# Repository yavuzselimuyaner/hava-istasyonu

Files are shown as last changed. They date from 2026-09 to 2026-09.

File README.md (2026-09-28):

# Weather Station

**English** · [Türkçe](README.tr.md)

A device that measures outdoor temperature, humidity and pressure, publishes the readings to the internet over Wi-Fi, and shows them on a browser page.

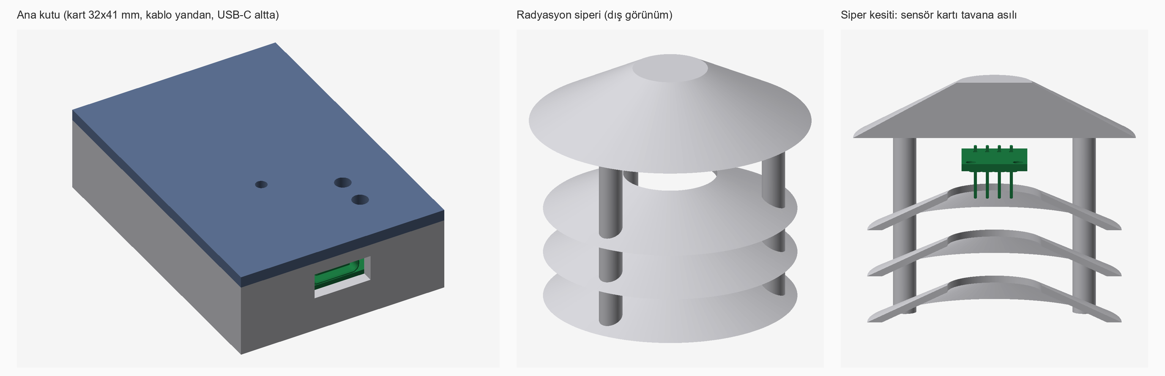
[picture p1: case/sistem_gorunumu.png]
Main enclosure and radiation shield


## What we built

### 1. Two boards
| Main board (32x41 mm) | Sensor board (14x16 mm) |
|---|---|
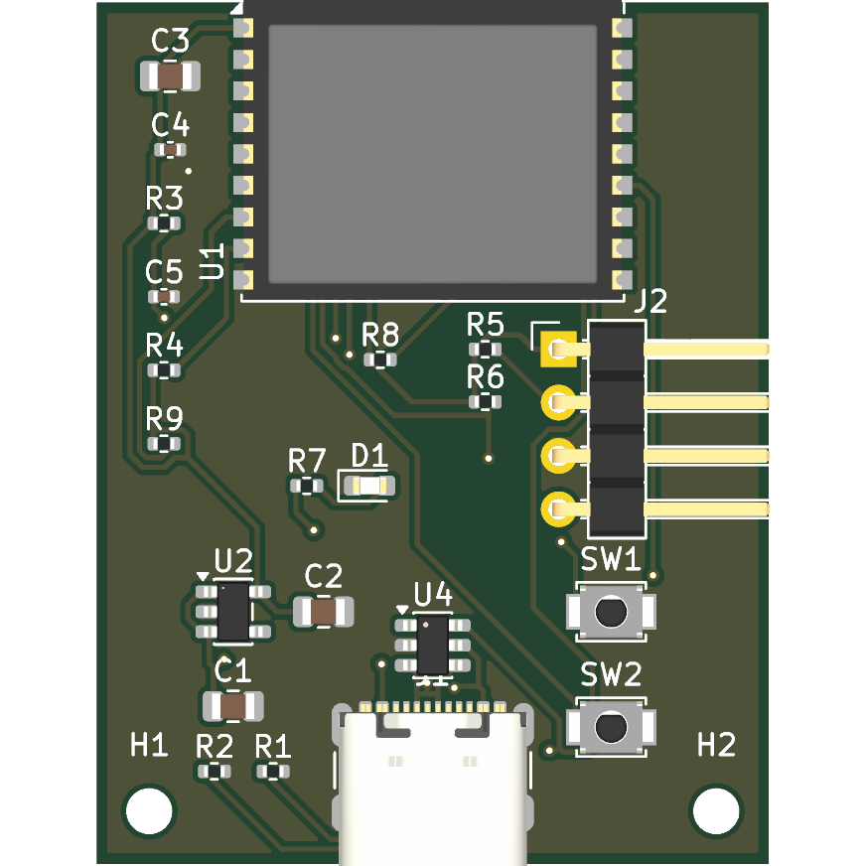
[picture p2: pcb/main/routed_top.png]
Main board
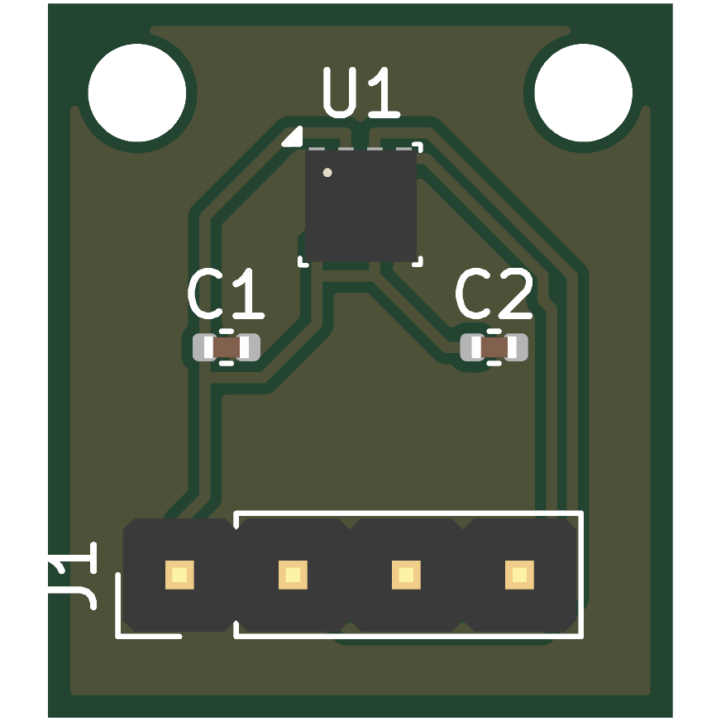
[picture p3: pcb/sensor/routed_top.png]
Sensor board
|  |  |

- **Main board:** ESP32-C3 (Wi-Fi processor module), USB-C, 3.3 V regulator, reset and boot buttons, status LED, and a 4-pin connector for the sensor. Held in the enclosure with two M2 screws.
- **Sensor board:** BME280 (temperature, humidity, pressure) and a connector. It is separate from the main board and connected by a cable, because the processor and regulator warm up and a sensor next to them would read the temperature too high.
- **Design decisions:** The antenna extends past the board edge (the manufacturer's recommendation). Pull-up resistors were added to IO2 and IO8, which set the ESP32-C3's boot mode (found during the datasheet audit). The connector is right-angled, so the cable exits sideways and the enclosure stays low. The first three pins of the connector match the order of common 3-wire sensor modules (VCC, DATA, GND).
- **Tools:** Circuit described in Python with SKiDL and turned into a KiCad schematic ([main board](pcb/main/hava_sematik.pdf), [sensor board](pcb/sensor/hava_sematik.pdf)); each board is built in KiCad from its schematic's netlist, and copper traces are auto-routed with Freerouting. Result: electrical rules check (ERC) 0 errors, design rules check (DRC) 0 violations, schematic and board match.

### 2. Enclosure and radiation shield
- **Main enclosure (37x54x15 mm):** openings for USB-C, the cable exit, the buttons and the LED.
- **Radiation shield (60 mm diameter, 52 mm high):** three conical plates and a roof, so the sun does not heat the sensor while air still flows through. The sensor board hangs from the roof and the cable exits at the bottom.
- Generated by scripts in FreeCAD, with dimensions read directly from the board. A **collision check** was run by intersecting KiCad's per-part 3D board model with the enclosure: no collisions.

### 3. Firmware
C with ESP-IDF. Connects to Wi-Fi, reads the sensor, and publishes the reading as JSON over MQTT (WebSocket + TLS, port 443). The sensor can be the BME280 (main board) or, as an alternative, a DHT22. A BME280 driver, the measurement compensation math, and DHT22 decoding were written.

### 4. Web page
A single-file page (`web/index.html`) that subscribes to the same MQTT topic, shows temperature, humidity and pressure, and displays the weather service's value next to them for comparison.

### 5. How we tested it
- **Datasheet audit (3 rounds):** Pin and circuit details of every part were compared with the datasheets; the issues found (unconnected strapping pins, a missing capacitor) were fixed.
- **Tests on a PC:** The BME280 math was compared with Bosch's datasheet example and the reference formula; the BME280 driver was run against a virtual sensor; DHT22 decoding was tested with datasheet examples.
- **Simulation (Wokwi):** Since the simulator has no BME280, readings were taken with an ESP32-S3 and a virtual DHT22, published over MQTT, and seen on the web page. A negative temperature (−17.9 °C) and about 3 minutes of continuous operation were tested.
- **Process:** The design and code were generated with an LLM (Claude); every step was checked with the tests above, and the issues they found were fixed.
- **Limitation:** Not yet tested on real hardware.

## Folders
| Folder | Contents |
|---|---|
| `pcb/main`, `pcb/sensor` | Main board and sensor board (KiCad, generation scripts) |
| `case` | Enclosure and radiation shield (FreeCAD scripts, images) |
| `firmware` | ESP-IDF project and tests |
| `web` | Browser page |
| `docs` | Design documents (`tasarim/`: requirements, part selection, datasheet audits, pin table) and build instructions (`CALISTIRMA.md`), in Turkish |

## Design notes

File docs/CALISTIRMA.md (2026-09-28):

# Çalıştırma ve yeniden üretme (Windows)

Gerekenler: KiCad 10 (`C:\Program Files\KiCad\10.0`), FreeCAD 1.1, Java 21, ESP-IDF v6.0.2, Python (SKiDL için `pcb/.venv`). Freerouting **v2.1.0** (Java 21 ile çalışan sürüm) `pcb/tools/` içinde olmalı (indirilmez, depoda yok).

## Kartlar (`pcb/main` veya `pcb/sensor` içinde)
Akış: SKiDL devre tanımı → **KiCad şematiği** → şematikten netlist → PCB yerleşimi → yol çizimi.
```
..\.venv\Scripts\python.exe gen_netlist.py
sh ../tools/check.sh .
"C:\Program Files\KiCad\10.0\bin\python.exe" build_board.py
"C:\Program Files\KiCad\10.0\bin\python.exe" route.py
"C:\Program Files\KiCad\10.0\bin\kicad-cli.exe" pcb drc --severity-error --schematic-parity -o drc_routed.rpt hava_routed.kicad_pcb
```
1. `gen_netlist.py`: devre tanımı (SKiDL) → `hava_skidl.net`.
2. `tools/check.sh` (Git Bash ile): `gen_schematic.py` ile `hava.kicad_sch` şematiğini üretir, KiCad ERC'sini çalıştırır (hata varsa durur), şematikten `hava.net` netlistini alır, bunun SKiDL netlistiyle bağlantı olarak birebir aynı olduğunu `tools/net_compare.py` ile doğrular ve `hava_sematik.pdf` çıktısını verir.
3. `build_board.py`: PCB'yi şematikten gelen `hava.net`'ten kurar; her footprint şematikteki sembolüne bağlanır.
4. `route.py`: Freerouting ile yollar → `hava_routed.kicad_pcb`.
5. DRC: `--schematic-parity` şematik ile kartın uyuştuğunu da kontrol eder.

Şematik KiCad'de `hava.kicad_pro` açılarak görülebilir. Sensör kartındaki tek ERC uyarısı beklenen bir durumdur: BME280'in SDO bacağı I2C adresini 0x76 yapmak için GND'ye bağlı; kütüphane bu bacağı "çift yönlü" tanımladığı için KiCad, GND'deki güç işaretiyle birlikte uyarı verir.
Freerouting deterministik değildir; sonuç her seferinde biraz farklı çıkar. Denemeden önce çalışan `hava_routed.kicad_pcb` dosyasını Git'e kaydet.

Pin tablosu (datasheet karşılaştırması için): `python pcb/pin_tablosu.py` çalıştırılınca `docs/tasarim/03-pin-tablosu.md` yeniden üretilir.

## Kutu ve siper (`case` içinde)
Sırasıyla `dump_board.py` (KiCad python), `make_main_case.py`, `make_shield.py`, `kicad-cli pcb export step ...`, `check_fit.py` (hepsi `freecadcmd` ile), `render_gorseller.py`. Komutlar betiklerin başındaki açıklamalarda.

## Firmware (`firmware` içinde, ESP-IDF PowerShell'inde)
```
idf.py -B build_c3 -D "SDKCONFIG=sdkconfig.c3" -D "IDF_TARGET=esp32c3" build
idf.py -B build_s3 -D "SDKCONFIG=sdkconfig.s3" -D "IDF_TARGET=esp32s3" build
idf.py -B build_wokwi -D "SDKCONFIG=sdkconfig.wokwi" -D "IDF_TARGET=esp32s3" -D "SDKCONFIG_DEFAULTS=sdkconfig.defaults;sdkconfig.defaults.esp32s3;sdkconfig.wokwi.defaults" build
```
Wi-Fi bilgileri: `idf.py menuconfig` → "Hava Sensor Dugumu" (bilgiler Git'e girmez). Wokwi için `firmware` klasörünü VS Code'da aç, "Wokwi: Start Simulator".

### T-Display-S3'e (gerçek donanım) yükleme
```
idf.py -B build_tdisplay -D "SDKCONFIG=sdkconfig.tdisplay" -D "IDF_TARGET=esp32s3" -D "SDKCONFIG_DEFAULTS=sdkconfig.defaults;sdkconfig.defaults.esp32s3;sdkconfig.tdisplay.defaults" menuconfig
```
Menüde Wi-Fi SSID/şifresini gir (bilgiler Git'e girmez), sonra:
```
idf.py -B build_tdisplay flash monitor
```
DHT22 verisi GPIO10'a, VCC 3V3'e, GND GND'ye bağlanır (SDA-VCC arası 10 kΩ pull-up önerilir). Kartın dahili ekranı (ST7789) otomatik devreye girer; sıcaklık, nem ve varsa basınç üç satır olarak gösterilir.

## Web
`web/index.html`'i tarayıcıda aç (MQTT.js CDN'den yüklenir). Yerel sunucu ile: `cd web && python -m http.server`.

## Testler (`firmware/test`, gcc)
```
gcc -Wall -Imock -o bme280_mock_test bme280_mock_test.c -lm
gcc -o dht22_test dht22_test.c
gcc -o bme_test bme_test.c -lm
```

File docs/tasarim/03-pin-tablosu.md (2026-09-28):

# Pin tablosu (karttan otomatik üretildi)

Bu tablo, şematikten (`pcb/*/hava.kicad_sch`) alınan `pcb/*/hava.net` dosyasından üretildi (`pcb/pin_tablosu.py`). Datasheet'lerdeki pin tablolarıyla karşılaştırma için: pin numarası, ad ve bağlı olduğu net. Karşılaştırma sonuçları `02-datasheet-denetimi.md` içinde.
Net adları: `+3V3`, `+5V`, `GND` güç hatları; `I2C_SDA/SCL` sensör; `USB_DP/DM` USB; `EN`, `BOOT` reset ve boot.

## Ana kart

### U1 — ESP32-C3-WROOM-02 (karşılaştır: modül datasheet'i pin tablosu; çip datasheet'i Tablo 3-3 boot)

| Pin | Adı (sembol) | Bağlı olduğu net |
|---|---|---|
| 1 | 3V3 | +3V3 |
| 2 | EN | EN |
| 3 | IO4 | I2C_SDA |
| 4 | IO5 | I2C_SCL |
| 7 | IO8 | IO8_PU |
| 8 | IO9 | BOOT |
| 9 | GND | GND |
| 11 | IO20/RXD | LED_IO |
| 13 | IO18 | USB_DM |
| 14 | IO19 | USB_DP |
| 16 | IO2 | IO2_PU |
| 19 | GND | GND |

Strapping kontrolü: **IO2 (pin 16)** ve **IO8 (pin 7)** birer 10 kΩ ile +3V3'e, **IO9 (pin 8)** BOOT hattına (10 kΩ pull-up + buton) bağlı olmalı. Tablodaki `IO2_PU` ve `IO8_PU` netleri R8 ve R9 dirençlerinin diğer ucudur; aşağıdaki direnç tablosunda R8/R9 satırlarında pin 1 = +3V3 görmelisin.

### U2 — AP2112K-3.3 (karşılaştır: AP2112 datasheet 'Pin Descriptions', SOT25)

| Pin | Adı (sembol) | Bağlı olduğu net |
|---|---|---|
| 1 | VIN | +5V |
| 2 | GND | GND |
| 3 | EN | +5V |
| 5 | VOUT | +3V3 |

### U4 — USBLC6-2SC6 (USB koruması)

| Pin | Adı (sembol) | Bağlı olduğu net |
|---|---|---|
| 1 | I/O1 | USB_DP |
| 2 | GND | GND |
| 3 | I/O2 | USB_DM |
| 4 | I/O2 | USB_DM |
| 5 | VBUS | +5V |
| 6 | I/O1 | USB_DP |

### J2 — sensör konnektörü (4 pin)

| Pin | Adı (sembol) | Bağlı olduğu net |
|---|---|---|
| 1 | 1 | +3V3 |
| 2 | 2 | I2C_SDA |
| 3 | 3 | GND |
| 4 | 4 | I2C_SCL |

### J1 — USB-C (CC1/CC2 pinleri her biri 5,1 kΩ ile GND'ye bağlı olmalı)

| Pin | Adı (sembol) | Bağlı olduğu net |
|---|---|---|
| A1 |  | GND |
| A12 |  | GND |
| A4 |  | +5V |
| A5 |  | USB_CC1 |
| A6 |  | USB_DP |
| A7 |  | USB_DM |
| A9 |  | +5V |
| B1 |  | GND |
| B12 |  | GND |
| B4 |  | +5V |
| B5 |  | USB_CC2 |
| B6 |  | USB_DP |
| B7 |  | USB_DM |
| B9 |  | +5V |
| SH |  | GND |

### Dirençler ve kondansatörler (değer → bağlı net çiftleri)

| Ref | Değer | Pin 1 | Pin 2 |
|---|---|---|---|
| C1 | 10uF | +5V | GND |
| C2 | 10uF | +3V3 | GND |
| C3 | 10uF | +3V3 | GND |
| C4 | 100nF | +3V3 | GND |
| C5 | 1uF | EN | GND |
| R1 | 5.1k | USB_CC1 | GND |
| R2 | 5.1k | USB_CC2 | GND |
| R3 | 10k | +3V3 | EN |
| R4 | 10k | +3V3 | BOOT |
| R5 | 4.7k | +3V3 | I2C_SDA |
| R6 | 4.7k | +3V3 | I2C_SCL |
| R7 | 1k | LED_IO | LED_A |
| R8 | 10k | +3V3 | IO2_PU |
| R9 | 10k | +3V3 | IO8_PU |

## Sensör kartı

### U1 — BME280 (karşılaştır: Bosch datasheet Bölüm 7, Tablo 35 ve Şekil 17)

| Pin | Adı (sembol) | Bağlı olduğu net |
|---|---|---|
| 1 | GND | GND |
| 2 | CSB | +3V3 |
| 3 | SDI | I2C_SDA |
| 4 | SCK | I2C_SCL |
| 5 | SDO | GND |
| 6 | VDDIO | +3V3 |
| 7 | GND | GND |
| 8 | VDD | +3V3 |

Beklenen (I2C): **CSB → +3V3**, **SDO → GND** (adres 0x76), VDD ve VDDIO ikisi de +3V3, iki pin GND.

### J1 — sensör konnektörü (ana kartın J2'si ile aynı sırada olmalı)

| Pin | Adı (sembol) | Bağlı olduğu net |
|---|---|---|
| 1 | 1 | +3V3 |
| 2 | 2 | I2C_SDA |
| 3 | 3 | GND |
| 4 | 4 | I2C_SCL |

### Kondansatörler

| Ref | Değer | Pin 1 | Pin 2 |
|---|---|---|---|
| C1 | 100nF | +3V3 | GND |
| C2 | 100nF | +3V3 | GND |

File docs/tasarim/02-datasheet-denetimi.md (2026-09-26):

# Datasheet denetimi

Kartlardaki bağlantılar ve değerler, parçaların datasheet'leriyle karşılaştırıldı. Kartın pin ve bağlantı listesi `03-pin-tablosu.md` dosyasında (karttan otomatik üretilir).

## Yöntem
- Datasheet metinleri PDF'ten çıkarıldı; şemalar, çizimler ve tablo görüntüleri sayfa sayfa görüntüye çevrilip okundu.
- Sayısal değerler her zaman PDF'in kendisinden alındı. Bir boot tablosunun otomatik bir özetle yanlış aktarılması, bunun gerekli olduğunu gösterdi.
- Karttaki her pin ve değer, datasheet'teki ilgili tabloya karşı işaretlendi.

| Belge | Sürüm |
|---|---|
| ESP32-C3 Series Datasheet | v2.4 |
| ESP32-C3-WROOM-02 ve WROOM-02U Datasheet | v1.7 |
| BME280 Data sheet (Bosch Sensortec) | dosya revizyonu 1.24 (sayfa altbilgisi DS001-23 rev 1.23) |
| AP2112 (Diodes Inc.) | DS39724 Rev. 2-2, Haziran 2017 |
| GCT USB4105 Product Drawing | Rev B3 |
| USBLC6-2 (STMicroelectronics) | Doc ID 11265 Rev 5, Ekim 2011 (üçüncü taraf kopyası) |

## Sonuçlar (6 kontrolün 6'sı uyuşuyor)

### 1) Strapping pinleri ve açılış modu
- **Kaynak:** Çip datasheet Tablo 3-1 ve 3-3 (s.30-31); modül datasheet Tablo 4-3.
- **Datasheet:** SPI boot: GPIO2=1, GPIO8=herhangi, GPIO9=1. İndirme modu: GPIO2=1, **GPIO8=1**, GPIO9=0. Varsayılan durum: GPIO2 ve GPIO8 "floating", GPIO9 zayıf pull-up. GPIO2'nin glitch'lere karşı yukarı çekilmesi önerilir.
- **Kart:** IO2 → 10 kΩ → +3V3; IO8 → 10 kΩ → +3V3; IO9 → BOOT hattı (10 kΩ pull-up ve buton).
- **Referans tasarım:** Modül datasheet Şekil 9-1 (s.34): IO2 ve IO8 için 10 kΩ ile VDD33'e çekme, IO9 için "Boot Option" başlığı. Kart referansla aynı. Modülün kendi şematiğinde (Şekil 8-1) EN, IO2 ve IO8 için dahili direnç yok; dış pull-up gerekli.

### 2) ESP32-C3-WROOM-02 modülü
- **Kaynak:** Modül datasheet Tablo 3-1 (s.10-11), Tablo 6-2, 6-4, Şekil 9-1.
- **Pinler:** 1=3V3, 2=EN, 3=IO4 (SDA), 4=IO5 (SCL), 7=IO8, 8=IO9, 9 ve 19=GND, 11=RXD (IO20), 12=TXD (IO21), 13=IO18 (USB D−), 14=IO19 (USB D+), 16=IO2. Pin tablosuyla birebir aynı.
- **EN:** "EN pini floating bırakılmamalı"; önerilen RC 10 kΩ ve 1 µF (s.34 metni). Kartta 10 kΩ ve 1 µF. Aynı sayfadaki şekilde C4 = 0,1 µF yazıyor; metin ile şekil tutarsız, metne uyuldu.
- **Güç:** VDD33 3,0–3,6 V; harici kaynak en az 0,5 A (Tablo 6-2). Wi-Fi tepe akımı 345 mA (802.11b 1 Mbps @20,5 dBm, Tablo 6-4). 600 mA'lik regülatör yeterli.
- **Besleme kondansatörleri:** Referansta 10 µF ve 0,1 µF; kartta 10 µF ve 100 nF.
- **USB hatları:** Referans tasarımda D+ ve D− üzerinde 0 Ω seri direnç var; kartta seri direnç yok, USBLC6 koruması var. Datasheet ikisini de zorunlu kılmıyor.

### 3) BME280
- **Kaynak:** Bölüm 7, Tablo 35 (pin açıklaması), Şekil 17 (I2C bağlantısı), Şekil 21 (lehim deseni, s.43).
- **Pinler:** 1=GND, 2=CSB, 3=SDI, 4=SCK, 5=SDO, 6=VDDIO, 7=GND, 8=VDD. I2C için CSB→VDDIO, SDO→GND (adres 0x76), VDD ve VDDIO için ayrı 100 nF, pull-up için 4,7 kΩ. Kartlarla aynı.
- **Footprint:** Önerilen lehim deseni: pad 0,5 x 0,35 mm, aralık 0,65 mm, merkez ofseti 1,025 mm. KiCad footprint'i (Bosch_LGA-8_2.5x2.5mm_P0.65mm_ClockwisePinNumbering) aynı boyutlarda, 90° döndürülmüş ve pin 1 konumu doğru.

### 4) AP2112K-3.3 (SOT25)
- **Kaynak:** Sayfa 2 (Pin Descriptions ve Blok Şeması), Not 4, Mutlak Azami Değerler, Önerilen Çalışma Koşulları.
- **Pinler:** 1=VIN, 2=GND, 3=EN, 5=VOUT. Blok şemada (D = SOT25) aynı numaralar. 4. pin datasheet tablosunda tanımlı değil, bağlantısız bırakıldı.
- **Değerler:** Önerilen VIN 2,5–6,0 V, mutlak azami 6,5 V (USB 5 V için uygun). Tipik uygulama giriş ve çıkışta 1 µF; 1 µF seramikse X7R veya X5R (Not 4). θJA (SOT25) = 184 °C/W. EN yüksek eşiği 1,5 V (kartta EN, VIN'e bağlı).
- **Kondansatör:** Datasheet yalnızca 1 µF'ı örnekliyor, üst sınır vermiyor. Kartta 10 µF (X5R/X7R seçilmeli); bir tasarım tercihi, datasheet'le çelişmez.

### 5) USB-C alıcı (GCT USB4105)
- **Kaynak:** Product Drawing, sayfa 1, pin tablosu ve "Recommended PCB Layout" ölçüleri.
- **Pinler:** A1, A12, B1, B12 = GND; A4, A9, B4, B9 = VBUS; A5 = CC1; B5 = CC2; A6/B6 = D+; A7/B7 = D−; A8 = SBU1; B8 = SBU2; kabuk = GND. Karttaki bağlantılarla birebir aynı (SBU pinleri bağlantısız).
- **Footprint ölçüleri:** Önerilen PCB deseni ile KiCad footprint'i sayısal karşılaştırıldı: pad merkezleri ±3,20 / ±2,40 / ±1,75 / ±1,25 / ±0,75 / ±0,25 mm, pad genişlikleri 0,60 ve 0,30 mm, pad boyu 1,15 mm, konumlandırma delikleri Ø0,65 mm (aralık 5,78 mm), kabuk delikleri 8,64 mm aralıkta (üstte 1,0x2,1 mm oval, delik 0,6x1,7; altta 1,0x1,8 mm oval, delik 0,6x1,4) ve delikler arası 4,18 mm: hepsi çizimle aynı.
- **Kart kenarı:** Çizimde kart kenarı alt kabuk delik merkezinin 2,60 mm ötesinde; kartta konnektör kenardan 3,5 mm içeride, çizime göre 3,675 mm olmalı. Kabuk 0,175 mm fazla dışarı taşıyor; çizimin ±0,05 mm toleransının dışında, bu bilinen bir sapma olarak not edildi.
- **CC dirençleri:** Çizimde yok. USB Type-C kuralı: cihaz (sink) tarafında her CC pini ayrı ayrı 5,1 kΩ ile GND'ye bağlanır. Kartta iki ayrı 5,1 kΩ direnç.

### 6) USBLC6-2SC6 (SOT23-6L)
- **Kaynak:** ST datasheet, Şekil 1 (üstten görünüş, fonksiyonel şema).
- **Pinler:** 1 ve 6 = I/O1, 2 = GND, 3 ve 4 = I/O2, 5 = VBUS. Kartta pin 1 ve 6 USB_DP, pin 3 ve 4 USB_DM, pin 2 GND, pin 5 +5V: birebir aynı (`03-pin-tablosu.md`).
- **Belge:** ST'nin resmi sitesi bu denetimde açılamadı; içeriği ST datasheet'inin bir kopyasından (üçüncü taraf, ST logolu, Doc ID 11265 Rev 5) okundu. Şekil ve pin numaraları sayfa görüntüsünden doğrulandı.

## Denetimde bulunan ve düzeltilen hatalar
| Bulgu | Düzeltme |
|---|---|
| IO8 bağlantısız bırakılmıştı; indirme modu için GPIO8=1 şart, varsayılanı belirsiz (floating) | IO8'e 10 kΩ pull-up |
| IO2 bağlantısız; datasheet yukarı çekilmesini öneriyor | IO2'ye 10 kΩ pull-up |
| BME280 için tek 100 nF vardı; Bosch VDD ve VDDIO için ayrı ayrı gösteriyor | İkinci 100 nF eklendi |
| Modülün GPIO sayısı yanlış aktarılmıştı (22 yerine 15) | Düzeltildi |
| AP2112 SOT25 4. pini "NC" diye yazılmıştı; datasheet tanımlamıyor | Belgeler düzeltildi |
| Wi-Fi tepe akımı çip datasheet'inde 335 mA, modülde 345 mA | Modül değeri esas alındı |
| Anten kartın içinde kalmıştı; üretici anteni kart kenarından dışarı taşırmayı öneriyor | Modül kaydırıldı, anten kart dışında |

## Hesaplar
- **I2C kablo yükü:** Standart mod için yükselme süresi üst sınırı 1000 ns ve hat sığası üst sınırı 400 pF (I2C spesifikasyonundan bilgi; belge bu çalışmada açılmadı). 4,7 kΩ pull-up ile ~250 pF bütçe var. 40 cm kablo yaklaşık 20 pF, iki cihaz girişi birkaç on pF: bütçenin çok altında. Kablo 1 m'yi geçmemeli.
- **Regülatör ısınması:** SOT25 θJA = 184 °C/W, giriş-çıkış farkı 1,7 V. Ortalama 100 mA'de ~0,17 W, yaklaşık 31 °C yükselme; 345 mA tepe akım kısa süreli.
- **Kutu ve siper çakışması:** KiCad'in parçalı 3D kart modeli FreeCAD'de kutu ve siperle kesiştirildi: çakışma yok. Kontrolün doğruluğu, kartı bilerek duvara kaydırıp çakışmanın bulunmasıyla sınandı.

## Açıkta kalanlar ve bilinen sınırlar
- **USB Type-C 5,1 kΩ kuralı:** Birkaç ikincil kaynakla teyit edildi; USB-IF spesifikasyonunun kendisi açılmadı.
- **Anten yasak bölgesi:** Ölçü, footprint'in courtyard'ından alındı; Espressif donanım tasarım rehberinin ilgili bölümü ayrıca incelenmedi.
- **USB izleri:** Ana kartta modülün altından geçiyor; kritik hatlar için elle yönlendirme daha iyi olurdu.
- **Siper:** Yağmur koruması sınırlı (tavan ile en üst plaka arasında açık boşluk).
- **Kutu:** Vidalar modellenmedi; kapak sürtünmeli çıtayla oturur; anten çevresindeki plastiğin etkisi ölçülmedi.

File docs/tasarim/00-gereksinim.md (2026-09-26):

# Gereksinim

Dışarıdaki bir sensörle sıcaklık, nem ve basıncı ölçen ve bu bilgiyi internete yayınlayan bir cihaz tasarla. Bilgi bir tarayıcı sayfasında görülebilmeli. Cihaz Wi-Fi ile bağlanacak, USB-C ile beslenecek. Sensör, cihazın ısınan parçalarından uzakta ve güneşten korunmuş olmalı: sensör ayrı küçük bir kartta, kabloyla bağlı olacak. Kartlar 2 katmanlı olacak. Çıktılar: KiCad kartları, kutu ve sensör koruması (radyasyon siperi), firmware ve basit bir web sayfası.

## Kısıtlar ve kararlar
- **Kablosuz bağlantı:** Wi-Fi (2,4 GHz). Anten performansı için hazır, sertifikalı bir modül kullanılır.
- **Güç:** USB-C, 5 V. Kart üzerinde 3,3 V'a indirilir.
- **Ölçüm:** Sıcaklık, bağıl nem, basınç; tek bir I2C sensörüyle.
- **Isıl ayrım:** İşlemci ve regülatör ısınır; sensör bu ısıdan ve doğrudan güneşten uzak durmalı. Bu yüzden sensör ana karttan ayrı, kabloyla bağlı bir kartta.
- **Haberleşme:** Ölçümler MQTT ile yayınlanır (WebSocket ve TLS üzerinden, 443 portu), tarayıcı sayfası aynı konuyu dinler.
- **Web sayfası:** Bilerek çok basit; tek dosya, sunucu ve veri tabanı yok.
- **Mekanik:** Kart kutuya vidayla sabitlenir (2 adet M2 montaj deliği); sensör kartı da kendi montaj deliklerine sahiptir.

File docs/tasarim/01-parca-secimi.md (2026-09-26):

# Parça seçimi

Her parça için seçilen ve elenen alternatifler ve gerekçe. Datasheet doğrulaması `02-datasheet-denetimi.md` içinde.

## İşlemci (MCU)
| Aday | Değerlendirme |
|---|---|
| **ESP32-C3-WROOM-02** | Seçildi. Wi-Fi ve BLE içinde, sertifikalı PCB anten modülü, USB Serial/JTAG dahili (ek çip gerekmez), ucuz, KiCad'de sembol ve footprint hazır. Modülde 15 GPIO pini var, bu iş için yeterli. |
| ESP32-S3-WROOM-1 | Bu iş için gereksiz güçlü, daha pahalı ve daha yüksek akımlı. |
| ESP32-S2-MINI-1 | Wi-Fi var, BLE yok, C3'e göre belirgin bir avantajı yok. |
| RP2040 + ayrı Wi-Fi modülü | İki çip, ek flash ve kristal gerekir; karmaşıklık ve hata riski artar. |

Çıplak çip yerine hazır modül seçildi: anten, kristal ve flash zaten entegre ve sertifikalı; RF tasarımı yeniden yapılmıyor.

## Sensör
| Aday | Değerlendirme |
|---|---|
| **BME280** | Seçildi. Sıcaklık, nem ve basınç tek çipte, I2C, 2,5 x 2,5 mm LGA. |
| SHT31 / SHT4x + BMP280 | Nem ve sıcaklık doğruluğu daha iyi olabilir ama iki çip gerekir. |
| AHT20 + BMP280 | İki çip. |
| DHT22 | Basınç yok, tek tel protokol; firmware'de alternatif sensör olarak desteklenir. |

BME280'in kendi ısınması ölçümü etkileyebilir; bu yüzden ısı kaynaklarından uzak, ayrı bir kartta.

## Regülatör
| Aday | Değerlendirme |
|---|---|
| **AP2112K-3.3** | Seçildi. 600 mA, SOT-23-5, yaygın. Modülün en yüksek Wi-Fi akımı ~345 mA, önerilen harici kaynak akımı 0,5 A: yeterli. |
| ME6211C33M5 | 500 mA; marj daha dar. |
| XC6220B331MR | 700 mA; daha pahalı. |

## USB
- **USB-C alıcı (GCT USB4105, 16 pin, USB 2.0):** Güç ve programlama/log.
- **CC1 ve CC2:** Her biri ayrı ayrı 5,1 kΩ ile GND'ye (cihaz tarafı, 5 V).
- **USBLC6-2SC6:** USB veri hatlarını ve VBUS'ı ESD'ye karşı korur.

## Diğer parçalar
- **EN devresi:** 10 kΩ pull-up ve 1 µF (üretici önerisi), reset butonu.
- **Boot:** IO9 için buton ve 10 kΩ pull-up.
- **Strapping pull-up'ları:** IO2 ve IO8 için 10 kΩ (açılış modunu belirleyen pinler).
- **I2C pull-up'ları:** SDA ve SCL için 4,7 kΩ.
- **Kondansatörler:** 3V3 hattında 10 µF ve 100 nF; regülatörde giriş ve çıkışta 10 µF; BME280 için iki adet 100 nF (VDD ve VDDIO).
- **Durum LED'i** ve 1 kΩ direnç.
- **Sensör konnektörü:** 1x4, 2,54 mm, dik açılı (kablo yandan çıksın, kutu alçak kalsın). Pin sırası: 1=3V3, 2=SDA/DATA, 3=GND, 4=SCL; ilk üç pin yaygın 3 telli sensör modüllerinin (VCC, DATA, GND) sırasına denk gelir.
- **Montaj delikleri:** Her kartta 2 adet M2.

## Sensör kartı
BME280, 2 x 100 nF, aynı 4 pinli konnektör ve 2 montaj deliği. I2C pull-up dirençleri ana kartta.

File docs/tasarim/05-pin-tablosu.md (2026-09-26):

# Pin tablosu (karttan otomatik üretildi)

Bu tablo `pcb/*/hava.net` dosyasından üretildi (`pcb/pin_tablosu.py`). Datasheet'teki pin tablosuyla yan yana koyup **kendi gözünle** karşılaştır: pin numarası, ad ve bağlı olduğu net uyuşuyor mu?
Net adları: `+3V3`, `+5V`, `GND` güç hatları; `I2C_SDA/SCL` sensör; `USB_DP/DM` USB; `EN`, `BOOT` reset ve boot.

## Ana kart

### U1 — ESP32-C3-WROOM-02 (karşılaştır: modül datasheet'i pin tablosu; çip datasheet'i Tablo 3-3 boot)

| Pin | Adı (sembol) | Bağlı olduğu net |
|---|---|---|
| 1 | 3V3 | +3V3 |
| 2 | EN | EN |
| 3 | IO4 | I2C_SDA |
| 4 | IO5 | I2C_SCL |
| 7 | IO8 | N$4 |
| 8 | IO9 | BOOT |
| 9 | GND | GND |
| 11 | IO20/RXD | LED_IO |
| 13 | IO18 | USB_DM |
| 14 | IO19 | USB_DP |
| 16 | IO2 | N$3 |
| 19 | GND | GND |

Strapping kontrolü: **IO2 (pin 16)** ve **IO8 (pin 7)** birer 10 kΩ ile +3V3'e, **IO9 (pin 8)** BOOT hattına (10 kΩ pull-up + buton) bağlı olmalı. Tablodaki `N$3` (IO2) ve `N$4` (IO8) otomatik adlı netlerdir: R8 ve R9 dirençlerinin diğer ucudur, aşağıdaki direnç tablosunda R8/R9 satırlarında pin 1 = +3V3 görmelisin.

### U2 — AP2112K-3.3 (karşılaştır: AP2112 datasheet 'Pin Descriptions', SOT25)

| Pin | Adı (sembol) | Bağlı olduğu net |
|---|---|---|
| 1 | VIN | +5V |
| 2 | GND | GND |
| 3 | EN | +5V |
| 5 | VOUT | +3V3 |

### U4 — USBLC6-2SC6 (USB koruması)

| Pin | Adı (sembol) | Bağlı olduğu net |
|---|---|---|
| 1 | I/O1 | USB_DP |
| 2 | GND | GND |
| 3 | I/O2 | USB_DM |
| 4 | I/O2 | USB_DM |
| 5 | VBUS | +5V |
| 6 | I/O1 | USB_DP |

### J2 — sensör konnektörü (4 pin)

| Pin | Adı (sembol) | Bağlı olduğu net |
|---|---|---|
| 1 | 1 | +3V3 |
| 2 | 2 | I2C_SDA |
| 3 | 3 | GND |
| 4 | 4 | I2C_SCL |

### J1 — USB-C (CC1/CC2 pinleri her biri 5,1 kΩ ile GND'ye bağlı olmalı)

| Pin | Adı (sembol) | Bağlı olduğu net |
|---|---|---|
| A1 |  | GND |
| A12 |  | GND |
| A4 |  | +5V |
| A5 |  | N$1 |
| A6 |  | USB_DP |
| A7 |  | USB_DM |
| A9 |  | +5V |
| B1 |  | GND |
| B12 |  | GND |
| B4 |  | +5V |
| B5 |  | N$2 |
| B6 |  | USB_DP |
| B7 |  | USB_DM |
| B9 |  | +5V |
| SH |  | GND |

### Dirençler ve kondansatörler (değer → bağlı net çiftleri)

| Ref | Değer | Pin 1 | Pin 2 |
|---|---|---|---|
| C1 | 10uF | +5V | GND |
| C2 | 10uF | +3V3 | GND |
| C3 | 10uF | +3V3 | GND |
| C4 | 100nF | +3V3 | GND |
| C5 | 1uF | EN | GND |
| R1 | 5.1k | N$1 | GND |
| R2 | 5.1k | N$2 | GND |
| R3 | 10k | +3V3 | EN |
| R4 | 10k | +3V3 | BOOT |
| R5 | 4.7k | +3V3 | I2C_SDA |
| R6 | 4.7k | +3V3 | I2C_SCL |
| R7 | 1k | LED_IO | N$5 |
| R8 | 10k | +3V3 | N$3 |
| R9 | 10k | +3V3 | N$4 |

## Sensör kartı

### U1 — BME280 (karşılaştır: Bosch datasheet Bölüm 7, Tablo 35 ve Şekil 17)

| Pin | Adı (sembol) | Bağlı olduğu net |
|---|---|---|
| 1 | GND | GND |
| 2 | CSB | +3V3 |
| 3 | SDI | I2C_SDA |
| 4 | SCK | I2C_SCL |
| 5 | SDO | GND |
| 6 | VDDIO | +3V3 |
| 7 | GND | GND |
| 8 | VDD | +3V3 |

Beklenen (I2C): **CSB → +3V3**, **SDO → GND** (adres 0x76), VDD ve VDDIO ikisi de +3V3, iki pin GND.

### J1 — sensör konnektörü (ana kartın J2'si ile aynı sırada olmalı)

| Pin | Adı (sembol) | Bağlı olduğu net |
|---|---|---|
| 1 | 1 | +3V3 |
| 2 | 2 | I2C_SDA |
| 3 | 3 | GND |
| 4 | 4 | I2C_SCL |

### Kondansatörler

| Ref | Değer | Pin 1 | Pin 2 |
|---|---|---|---|
| C1 | 100nF | +3V3 | GND |
| C2 | 100nF | +3V3 | GND |

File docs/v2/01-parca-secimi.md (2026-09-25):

# v1 Adım 1 — Parça Seçimi (Agent: parça seçici)

> **Not:** Bu belge eski (v1) tasarım için yazıldı: cihaz ekranlıydı ve internetten veri çekiyordu. **Ekran, pin planı ve "internetten çekme" kısımları ESKİDİR.** MCU/sensör/regülatör seçimi ve datasheet bulguları v2 için de GEÇERLİDİR. Güncel gereksinim: `00-gereksinim.md`.

Girdi: yalnızca 00-gereksinim.md. Kullanıcının elindeki donanım (T-Display, ESP32-S3) bilerek DİKKATE ALINMADI.
Kısıt notu: Ağ erişimi olmadan yazıldı; JLCPCB stok/fiyat ve datasheet değerleri DOĞRULANMADI. Bunlar denetçi adımının işidir (aşağıda işaretli).

## 1. MCU
| Aday | Artı | Eksi |
|---|---|---|
| ESP32-C3-WROOM-02 | Wi-Fi + BLE, sertifikalı anten modülü, tek çekirdek RISC-V yeterli, USB Serial/JTAG dahili (ek çip yok), ucuz, KiCad'de sembol+footprint var | 22 GPIO civarı; ihtiyaç için yeterli |
| ESP32-S3-WROOM-1 | Daha çok GPIO, daha güçlü | Bu iş için gereksiz, daha pahalı, daha yüksek akım |
| ESP32-S2-MINI-1 | Wi-Fi, USB OTG | BLE yok, C3'ten belirgin avantaj yok |
| RP2040 + ayrı Wi-Fi modülü | Ucuz MCU | İki çip, ek flash/kristal, karmaşıklık ve hata riski |

**Seçim: ESP32-C3-WROOM-02** (RF_Module:ESP32-C3-WROOM-02). Gerekçe: gereksinim yalnızca Wi-Fi, bir I2C sensörü ve bir SPI ekran; en az parçayla en düşük risk. Sertifikalı modül, anten tasarımı riskini kaldırır.
- Doğrulanacak: pin ataması (strapping GPIO2/8/9), USB pinleri GPIO18/19, tepe akım.

## 2. Sensör
| Aday | Not |
|---|---|
| BME280 | Sıcaklık+nem+basınç tek çipte, I2C, 2.5x2.5 mm LGA (elle lehimlenmez, montaj hizmetiyle olur) |
| SHT31/SHT4x + BMP280 | İki çip, daha iyi nem/sıcaklık doğruluğu, daha çok parça |
| AHT20 + BMP280 | Ucuz ama iki çip |

**Seçim: BME280** (Sensor:BME280). Gerekçe: gereksinim üç ölçümü istiyor, tek çip en az parça. Risk: kartın kendi ısısı sıcaklığı yükseltir, sensör ısı kaynaklarından uzağa ve kart kenarına konmalı; klon/sahte BME280 riski (BMP280 olarak çıkabilir).

## 3. Regülatör
| Aday | Not |
|---|---|
| AP2112K-3.3 | 600 mA, SOT-23-5, yaygın |
| ME6211C33M5 | 500 mA, çok yaygın ve ucuz |
| XC6220B331MR | 700 mA, daha pahalı |

**Seçim: AP2112K-3.3.** Gerekçe: Wi-Fi TX tepe akımı (~350 mA civarı C3 için) altında yeterli marj. Doğrulanacak: datasheet'te tepe akım ve dropout, çıkış kondansatörü gereksinimi.

## 4. USB-C
16 pinli USB 2.0 Type-C girişi (Connector:USB_C_Receptacle_USB2.0_16P), CC1/CC2 için 5.1 kΩ (5 V sink), D+/D− doğrudan C3'ün USB pinlerine. Ek ESD koruması (USBLC6-2SC6) eklenir.
- Doğrulanacak: JLCPCB'de montaj yapılan uygun bir 16P konnektör var mı, footprint uyumu.

## 5. Ekran (KARAR)
| Seçenek | Not |
|---|---|
| Harici 1.3" ST7789 SPI 240x240 modül, 8 pin header | Karta ekran flexi/FPC routing riski yok, modül ucuz ve yaygın |
| Karta doğrudan bağlı ekran (FPC) | Daha kompakt, ama FPC footprint ve sürücü riski yüksek |
| 0.96" OLED I2C | Sensörle aynı I2C hattı, az pin; ama küçük, hava verisi için yetersiz |

**Seçim: harici 1.3" ST7789 SPI modül, 8 pin header.** Gerekçe: yerleşim ve montaj riskini azaltır. Bu karar gereksinimde açık bırakıldığı için agent'a aittir.

## 6. Yardımcı parçalar
- Reset (EN) ve BOOT (GPIO9) butonları, 10 kΩ pull-up'lar, EN için 1 µF.
- I2C pull-up 4.7 kΩ ×2.
- Bypass kondansatörleri (MCU, sensör, regülatör giriş/çıkış).
- Durum LED'i + direnç.

## Denetçiye devredilen kontrol listesi
- [ ] ESP32-C3-WROOM-02 datasheet: pin isimleri, strapping, EN devresi, USB pinleri, anten keepout
- [ ] BME280 datasheet: adres seçimi (SDO), CSB pinini I2C modu için bağlama, güç/decoupling
- [ ] AP2112K datasheet: çıkış C değeri, EN kullanımı
- [ ] JLCPCB: parçaların montaj kataloğunda olup olmadığı, temel/genişletilmiş parça durumu

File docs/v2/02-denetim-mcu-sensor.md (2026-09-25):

# v1 Adım 2 — Denetim (Agent: denetçi)

> **Not:** Bu belge eski (v1) tasarım için yazıldı: cihaz ekranlıydı ve internetten veri çekiyordu. **Ekran, pin planı ve "internetten çekme" kısımları ESKİDİR.** MCU/sensör/regülatör seçimi ve datasheet bulguları v2 için de GEÇERLİDİR. Güncel gereksinim: `00-gereksinim.md`.

Kaynaklar: Espressif ESP32-C3-WROOM-02 datasheet (documentation.espressif.com), Bosch BME280 datasheet rev 1.24, Diodes AP2112 datasheet DS39724, JLCPCB parça sayfaları (arama sonuçları). Sonuçlar web aramasının özetlerine dayanır; kritik sayılar tasarım kilitlenmeden önce PDF'den elle teyit edilmelidir.

## Doğrulananlar
| Konu | Bulgu | Durum |
|---|---|---|
| C3 modül pinleri | 3V3=1, EN=2, IO4-7=3-6, IO8=7, IO9=8, GND=9, IO10=10, RXD/IO20=11, TXD/IO21=12, IO18(USB D-)=13, IO19(USB D+)=14, IO3=15, IO2=16, IO1=17, IO0=18, GND=19 | KiCad sembolü ve footprint ile TAM UYUMLU |
| Strapping | GPIO2, GPIO8, GPIO9 | Doğrulandı; bu üç pin sinyal olarak kullanılmayacak (GPIO9 = BOOT butonu) |
| USB | GPIO18/19 dahili USB Serial/JTAG; GPIO olarak yeniden atanırsa USB-JTAG kapanır | Doğrulandı; bu iki pin USB'ye ayrılmalı |
| EN devresi | Önerilen RC: 10 kΩ + 1 µF | Doğrulandı, taslakla aynı |
| BME280 I2C | CSB → VDDIO ile I2C modu; SDO GND ise 0x76, VDDIO ise 0x77; SDO bağlantısız bırakılamaz | Doğrulandı, taslakla aynı |
| AP2112 | 600 mA (min) sürekli akım; çıkışta 1 µF X7R/X5R önerilir | Doğrulandı; planlanan 10 µF ile uyumluluk (ESR/stabilite) datasheet'ten ayrıca kontrol edilecek |

## Bulunan hatalar (parça seçici agent'ın yanlışları)
1. **"22 GPIO" iddiası yanlış.** Çip 22 GPIO'ya sahip ama WROOM-02 modülünde 15 GPIO pini var (IO0-IO10, RXD/IO20, TXD/IO21, IO18, IO19).
2. **Güç marjı ince.** Datasheet dış kaynak için en az 0.5 A istiyor; AP2112K-3.3'ün garantili akımı 600 mA. Marj yalnızca 100 mA. Kabul edilebilir ama not düşülmeli: yeterli çıkış kondansatörü ve kısa yol; sorun çıkarsa daha güçlü LDO.
3. **Pin bütçesi sıkı.** Kullanılabilir sinyal pini: IO0,1,3,4,5,6,7,10 (8 pin) + UART pinleri IO20,IO21 (USB konsol kullanıldığı için serbest) = 10. Strapping (2,8,9) ve USB (18,19) hariç.

## Pin planı (v1, onaylanacak)
| Sinyal | Pin |
|---|---|
| I2C SDA / SCL | IO4 / IO5 |
| LCD SCK / MOSI | IO6 / IO7 |
| LCD DC / CS | IO10 / IO3 |
| LCD RST / BL | IO1 / IO0 |
| Durum LED | IO20 |
| Kullanıcı butonu | IO21 |
| BOOT butonu | IO9 (strapping, bilerek) |
| EN | modül pin 2 |
| USB D-/D+ | IO18 / IO19 |
Kullanılmayan: IO2, IO8 (strapping, bilerek boş).

## Doğrulanamayanlar (insan / ek adım gerekiyor)
- JLCPCB: ESP32-C3-WROOM-02-N4 (C2934560) ve AP2112K-3.3TRG1 (C51118) katalogda var; **stok ve Basic/Extended durumu doğrulanamadı**. BME280 ve USB-C konnektör arama sonuçlarında bulunamadı, ayrıca aranacak.
- GPIO8/GPIO9 önyükleme seviyeleri ve download modu koşulu (bu özetten net çıkmadı).
- BME280 bypass kondansatör değeri: 100 nF değeri BMP280 datasheet'inden geliyor, BME280'de doğrudan görülmedi.
- Anten keepout ölçüleri: datasheet "noktalı çizgi" diyor, milimetre alınmadı; Espressif hardware design guidelines'a bakılmalı.
- C3 footprint pad 19 (GND) altında termal via'lar var; delik çapı ve üretici kurallarıyla DRC'de kontrol edilecek.

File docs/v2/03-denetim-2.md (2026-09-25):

# v1 Adım 6 — İkinci datasheet denetimi (Agent: denetçi)

> **Not:** Bu belge eski (v1) tasarım için yazıldı: cihaz ekranlıydı ve internetten veri çekiyordu. **Ekran, pin planı ve "internetten çekme" kısımları ESKİDİR.** MCU/sensör/regülatör seçimi ve datasheet bulguları v2 için de GEÇERLİDİR. Güncel gereksinim: `00-gereksinim.md`.

Yöntem: Datasheet PDF'leri araç tarafından diske kaydedildi ve `pdftotext` ile YEREL okundu. Web aracının özeti tek başına yeterli çıkmadı (aşağıdaki hata bölümüne bak).
Kaynaklar: ESP32-C3 Series Datasheet v2.4 (Espressif), BME280 Data sheet rev 1.23 (Bosch, BST-BME280-DS001-23), AP2112 DS39724 Rev 2-2 (Diodes), USBLC6-2 (ST, arama özeti).

## Bulunan tasarım hataları (düzeltildi)
| # | Bulgu | Kaynak | Düzeltme |
|---|---|---|---|
| 1 | **GPIO8 bağlantısız bırakılmıştı.** Joint Download Boot modu için GPIO8=1 şart; varsayılanı "floating" (belirsiz) | C3 datasheet Tablo 3-1 ve 3-3 | IO8'e 10 kΩ pull-up (R9) |
| 2 | **GPIO2 bağlantısız bırakılmıştı.** Datasheet, glitch'lere karşı yukarı çekilmesini öneriyor | Tablo 3-3 not 2 | IO2'ye 10 kΩ pull-up (R8) |
| 3 | **BME280 için tek 100 nF vardı.** Bosch VDD ve VDDIO için ayrı ayrı C1, C2 = 100 nF gösteriyor | Bosch şekil 17 ve notları | İkinci 100 nF (C7) eklendi |

Boot tablosu (Tablo 3-3): SPI boot: GPIO2=1, GPIO8=herhangi, GPIO9=1 · Joint download boot: GPIO2=1, GPIO8=1, GPIO9=0.

## Doğrulananlar
- **BME280 pinleri:** 1 GND, 2 CSB, 3 SDI, 4 SCK, 5 SDO, 6 VDDIO, 7 GND, 8 VDD. Bizim bağlantıyla birebir (CSB→VDDIO = I2C, SDO→GND = 0x76, pull-up 4.7 kΩ önerilen değer). Numaralandırma saat yönünde, alttan bakışta saat yönünün tersi (KiCad footprint'i "ClockwisePinNumbering", uyumlu).
- **BME280 besleme:** VDD 1.71-3.6 V (dalgalanma en çok 50 mVpp), VDDIO 1.2-3.6 V; 1 Hz zorlamalı modda ~3.6 µA. Sensörün ölçülen sıcaklığı "PCB sıcaklığına ve kendi ısınmasına bağlı, genelde ortamın üstünde" (dipnot 7): LDO'dan uzak yerleşimimiz mantıklı.
- **AP2112K (SOT25):** Pinler 1 VIN, 2 GND, 3 EN, 4 NC, 5 VOUT (KiCad sembolü uyumlu). 600 mA (min.) çıkış, 3.3 V sürümde dropout tipik 250 mV @600 mA. EN yüksek eşiği 1.5 V (VIN'e bağlamamız doğru). Çıkışta 1 µF ile kararlı (seramik/tantal); 1 µF seramik seçilirse X7R veya X5R. Bizim 10 µF için **BOM'da dielektrik X5R/X7R olmalı**.
- **Akım marjı:** C3 en yüksek Wi-Fi TX akımı 335 mA (802.11b, 21 dBm); dış kaynak için en az 0.5 A isteniyor. AP2112K'nın 600 mA'si yeterli (önceki "ince marj" endişesi yumuşadı).
- **USBLC6-2SC6:** Pinler 1 I/O1, 2 GND, 3 I/O2, 4 I/O2, 5 VBUS, 6 I/O1 (arama özeti; netlist ile uyumlu).
- **USB:** GPIO18/19 varsayılan olarak USB Serial/JTAG denetleyicisine bağlı.

## Yeni açık riskler
- **LDO ısınması:** SOT25 θJA = 184 °C/W. 5 V → 3.3 V farkı 1.7 V; ortalama 100 mA'de ~0.17 W, yaklaşık 31 °C yükselme; 335 mA tepe akım kısa süreli. Kart ısınırsa BME280'in sıcaklığı yüksek ölçülebilir; gerçek kartta ölçülmeli.
- AP2112 mutlak azami giriş gerilimi 6.5 V (USB 5 V için yeterli, dalgalanma marjı dar).
- 4 numaralı AP2112 pini NC; KiCad sembolünde yok, footprint'te pad var (bağlantısız kalır, sorun değil).

## LLM'in yaptığı hata (kayda değer)
Web aracı (WebFetch) ESP32-C3 boot tablosunu **yanlış** özetledi: "SPI boot: GPIO8=1; Download: GPIO8=0, GPIO9=1" dedi. PDF'in kendisinde doğru değerler: SPI boot GPIO8=herhangi, Download GPIO8=1 ve GPIO9=0. Aracın özeti, tablo yapısı bozulmuş metni yanlış eşledi. Ders: sayısal tablo değerleri özetten değil, kaynak metinden doğrulanmalı. AP2112 ve BME280 PDF'lerini de araç okuyamadı, yerel `pdftotext` ile okundu.

## Hâlâ insan/donanım gerektirenler
- ESP32-C3-WROOM-02 modülünün kendi datasheet'i (WROOM-02 pin tablosu ve dahili bileşenler) ayrıca; buradaki tablolar çip datasheet'inden.
- JLCPCB stok ve kütüphane uyumu (bu turda kapsam dışı).

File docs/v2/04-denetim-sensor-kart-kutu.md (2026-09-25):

# v2 Denetimi — sensör kartı, konnektör, kutu, DHT22 uyumu

Kapsam: v2'de yeni olan parçalar (sensör kartı, 4 pinli konnektör, kutu ve siper). Ana kartın MCU/regülatör/USB kısımları v1 denetimlerinde (docs/v1/02, 03) doğrulandı ve değişmedi.

## Doğrulananlar
| Konu | Sonuç | Kanıt |
|---|---|---|
| Sensör kartı devresi | BME280 pin bağlantısı (CSB→VDDIO = I2C, SDO→GND = 0x76) ve VDD/VDDIO için iki ayrı 100 nF Bosch şekil 17 ile birebir | Bosch BME280 datasheet rev 1.23 (yerel PDF okundu) |
| Pull-up yeri | Sensör kartında pull-up yok, ana kartta 4,7 kΩ (SDA ve SCL). Bosch da pull-up'ı bus tarafına bırakıyor ("normal değer 4.7 kΩ") | Aynı |
| Konnektör sırası | 1=3V3, 2=SDA, 3=GND, 4=SCL; ana kart ve sensör kartında aynı; netlist'te iki kartta da uyumlu (KiCad pad ağ adları kontrol edildi) | pcb/v2/*/hava.net |
| DHT22 uyumu | DHT22 besleme 3,3–6 V (3,3 V uygun), örnekleme en az 2 sn, başlangıç sinyali ≥800 µs low, güç verdikten sonra 1 sn bekle, ~5 kΩ pull-up gerekir (bizim 4,7 kΩ SDA pull-up'ı bunu sağlıyor) | DHT22/AM2302 datasheet arama sonuçları (Adafruit, SparkFun, Waveshare, EDN) |
| Kart–kutu çakışması | Parçalı 3D kart modeli ile ana kutu ve siper arasında çakışma yok; Dupont fişi ve kablo yer tutucusu da temiz | case/v2/check_fit_v2.py çıktısı |
| Kontrolün güvenilirliği | Negatif kontrol: kart bilerek duvara 5,6 mm kaydırılınca 112,9 mm³ çakışma bulundu; ayrıca kutu 10 mm iken kapak çıtasının USB-C'ye 0,4 mm çarptığını (2,8 mm³) yakaladı, kutu 11 mm yapıldı | Aynı |

## I2C kablo yükü (hesap, bu oturumda kaynak açılmadı)
Standart mod I2C için yükselme süresi üst sınırı 1000 ns ve hat sığası üst sınırı 400 pF (NXP UM10204'ten bilgi, PDF açılmadı). 4,7 kΩ pull-up ile 1000 ns bütçesi ≈ 250 pF verir. Dupont kablo ~50 pF/m varsayımıyla 40 cm kablo yaklaşık 20 pF, iki cihaz girişi de birkaç on pF: bütçenin çok altında. Kablo 1 m'yi geçmemeli.

## Açık riskler ve sınırlar
- **DHT22 modül pin sırası standart değil.** Bazı modüller (+, OUT, −), bazıları (S, +, −) sıralı. Gerçek modülün serigrafisi kontrol edilmeli ve M-F jumper ile doğru pinlere bağlanmalı; konnektörün 1,2,3 sırası her modüle doğrudan uymayabilir.
- **DHT22 zamanlaması** yazılımla (bit-bang) okunur ve bu oturumda donanımda test edilemedi.
- **Siperin yağmur koruması sınırlı:** tavan ile en üst plaka arasında 12 mm açık boşluk var (havalandırma için). Yağmurlu rüzgârda sensöre su sıçrayabilir; gerçek dış mekân kullanımı için değerlendirilmeli.
- **Kablo demeti çıkışı:** siperin alt ortasından açık; su geçirmezlik yok.
- **Sensör kartı radyasyon siperi içinde 3D baskı gerektirir;** malzeme (UV dayanımı) seçimi yapılmadı.
- **Ana kutunun vida bağlantısı:** kart 2 M2 vida ile bağlanacak (vidalar modellenmedi), kapak sürtünmeli çıta ile oturur.
- Kutuda anten çevresinde ~2 mm plastik boşluk bırakıldı; plastiğin anten performansına etkisi ölçülmedi.

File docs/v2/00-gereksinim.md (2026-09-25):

# v2 Gereksinim (güncel, doğru yön)

Dışarıdaki bir sensörle sıcaklık, nem ve basıncı ölçen ve bu bilgiyi internete yayınlayan bir cihaz tasarla. Bilgi bir tarayıcı sayfasında görülebilmeli. Cihaz Wi-Fi ile bağlanacak, USB-C ile beslenecek. Sensör, cihazın ısınan parçalarından uzakta ve güneşten korunmuş olmalı: sensör ayrı küçük bir kartta, kabloyla bağlı olacak. Kart 2 katmanlı olacak. Çıktı olarak KiCad kartları, kutu ve sensör koruması (radyasyon siperi), firmware ve basit bir web sayfası üret. Her parça seçimini gerekçesiyle yaz.

Notlar:
- Web sayfası bilerek çok basit: tek dosya, sunucu ve veri tabanı yok.
- Prototip, elde bulunan malzemelerle (LilyGO T-Display-S3, breadboard, jumper) ve en fazla tek yeni sensör alımıyla (DHT22) yapılabilmeli.
- Bu gereksinimin ilk sürümü ("internetten hava durumunu çeken ve ekranda gösteren") ilk cümlenin ters okunmasıydı; bkz. `docs/calisma-gunlugu.md` adım 25.

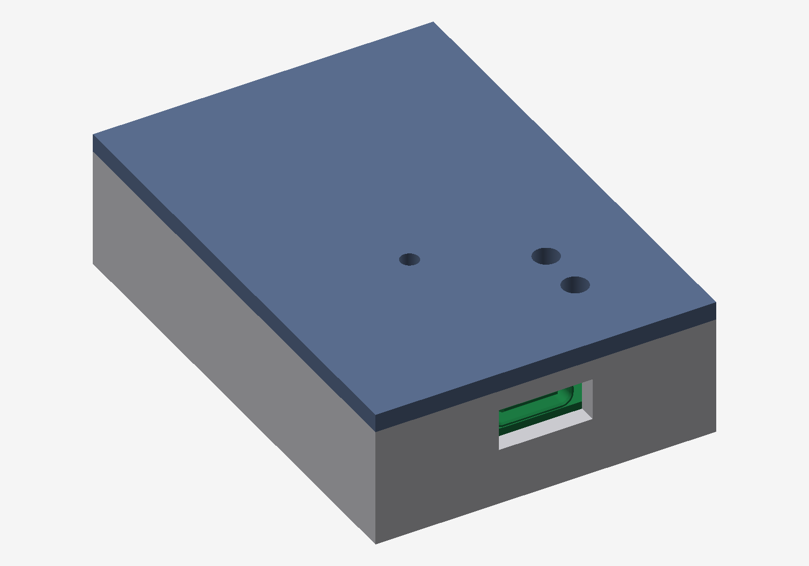
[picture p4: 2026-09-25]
case/ana_kutu_kapali.png

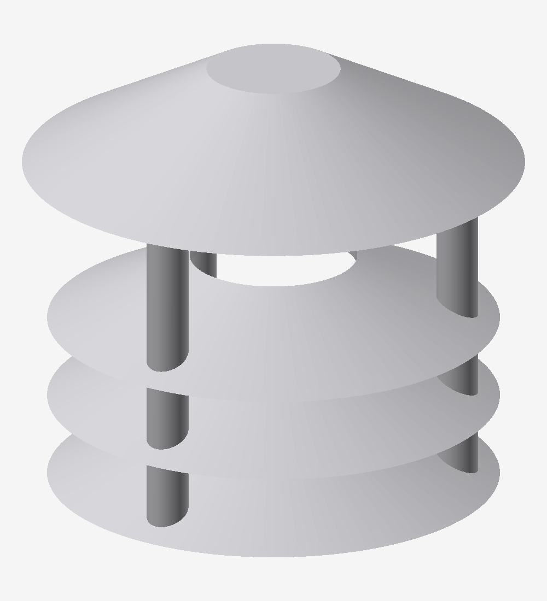
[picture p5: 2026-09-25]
case/siper_dis.png

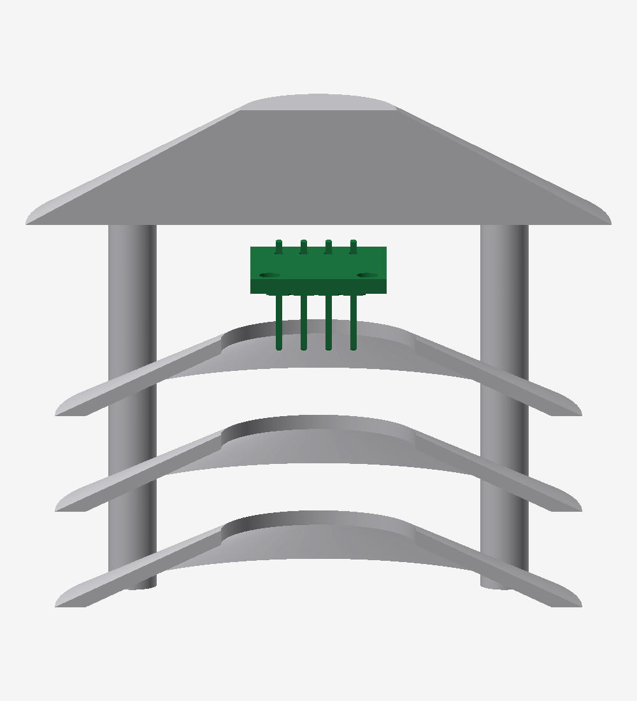
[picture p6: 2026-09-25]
case/siper_kesit.png

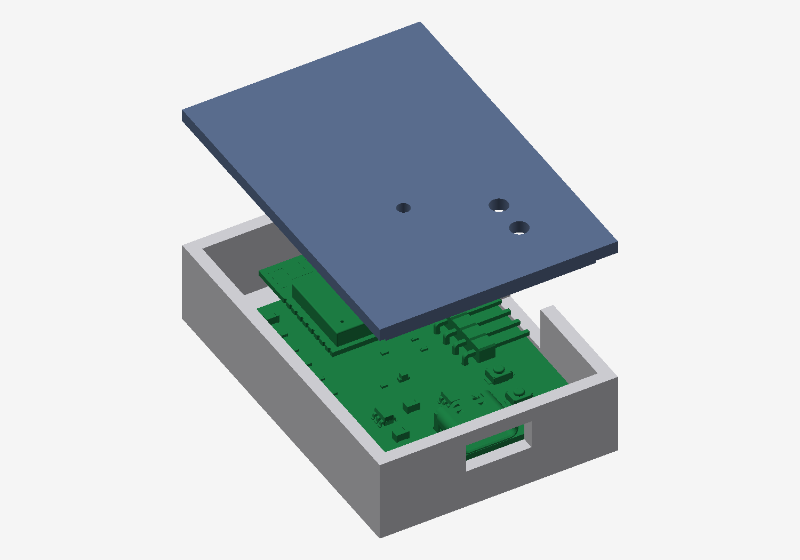
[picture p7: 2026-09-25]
case/ana_kutu_acik.png

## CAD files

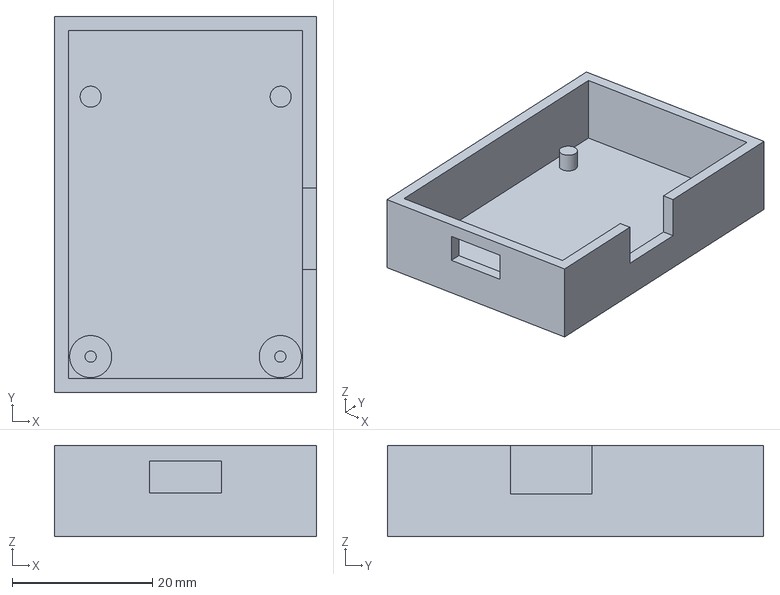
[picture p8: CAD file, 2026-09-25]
case/out/main_base.step
37.3 x 53.6 x 13.0 mm

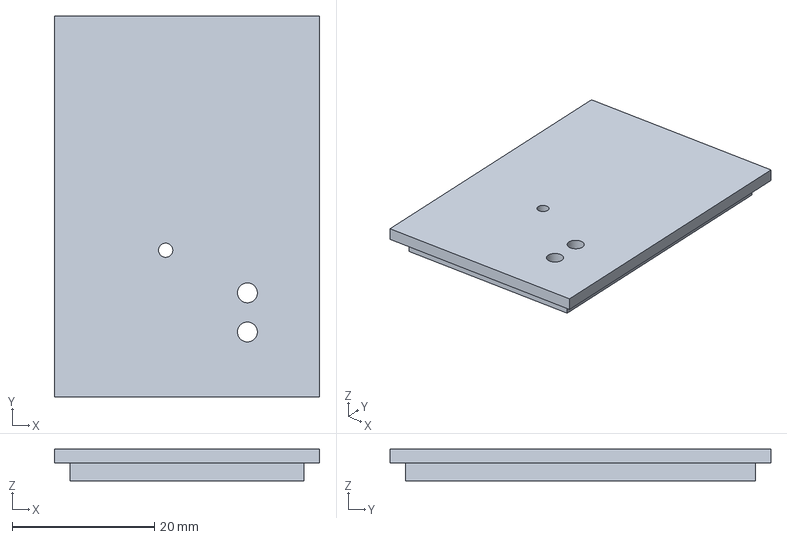
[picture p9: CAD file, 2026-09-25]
case/out/main_lid.step
37.3 x 53.6 x 4.50 mm

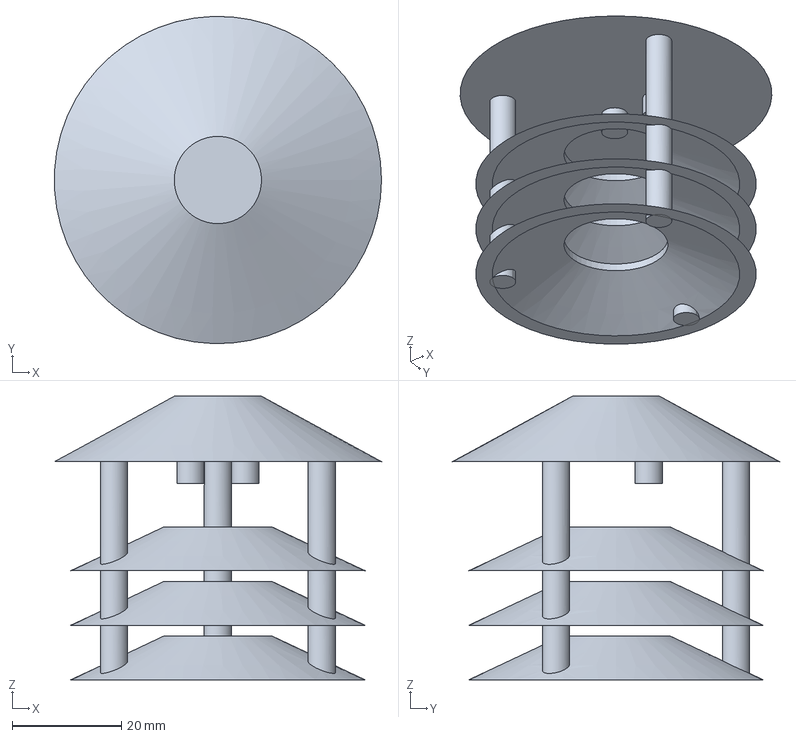
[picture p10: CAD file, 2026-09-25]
case/out/shield.step
60.0 x 60.0 x 52.0 mm

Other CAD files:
case/out/main_base.stl
case/out/main_lid.stl
case/out/shield.stl

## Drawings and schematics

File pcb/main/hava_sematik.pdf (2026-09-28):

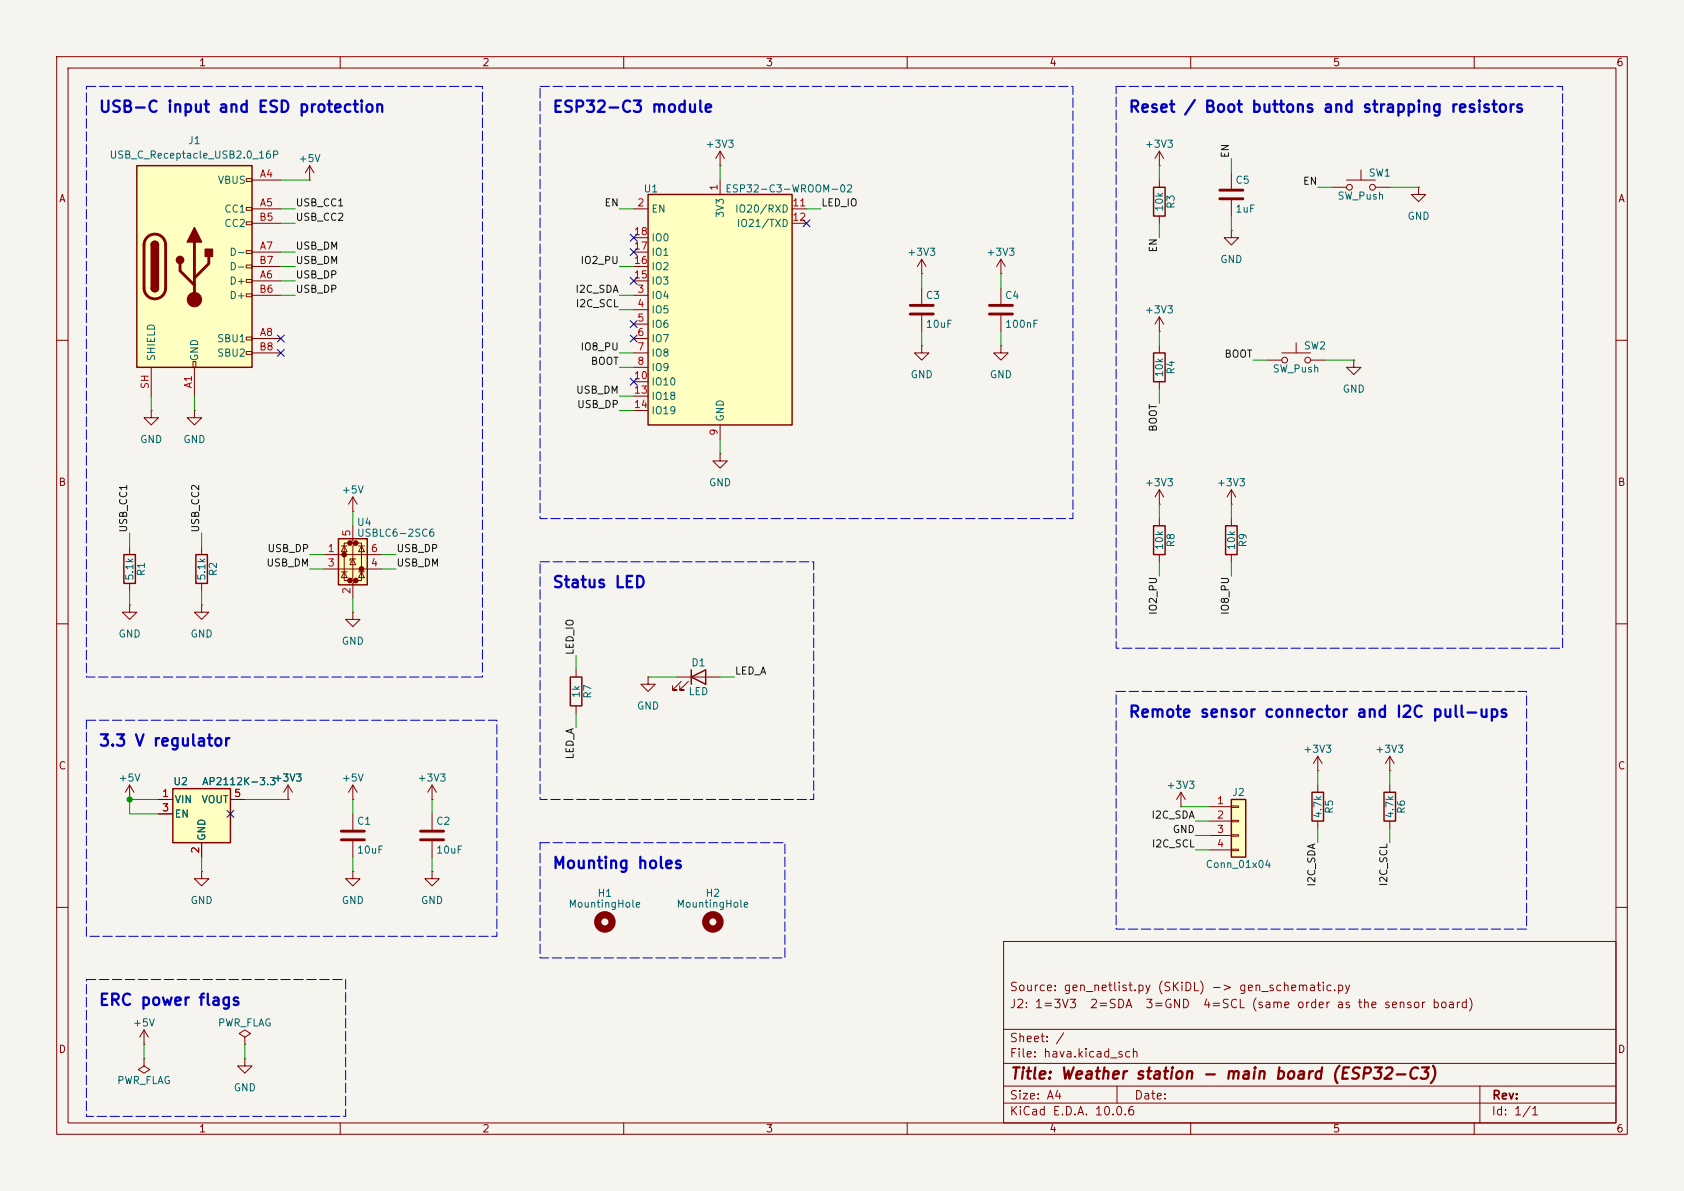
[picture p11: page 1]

USB-C input and ESD protection

Reset / Boot buttons and strapping resistors

Remote sensor connector and I2C pull-ups

ERC power flags PWR_FLAG | GND

J2: 1=3V3 2=SDA 3=GND 4=SCL (same order as the sensor board)

Sheet: /
File: hava.kicad_sch
Title: Weather station - main board (ESP32-C3)

Size: A4 | Rev:
KiCad E.D.A. 10.0.6 | Id: 1/1

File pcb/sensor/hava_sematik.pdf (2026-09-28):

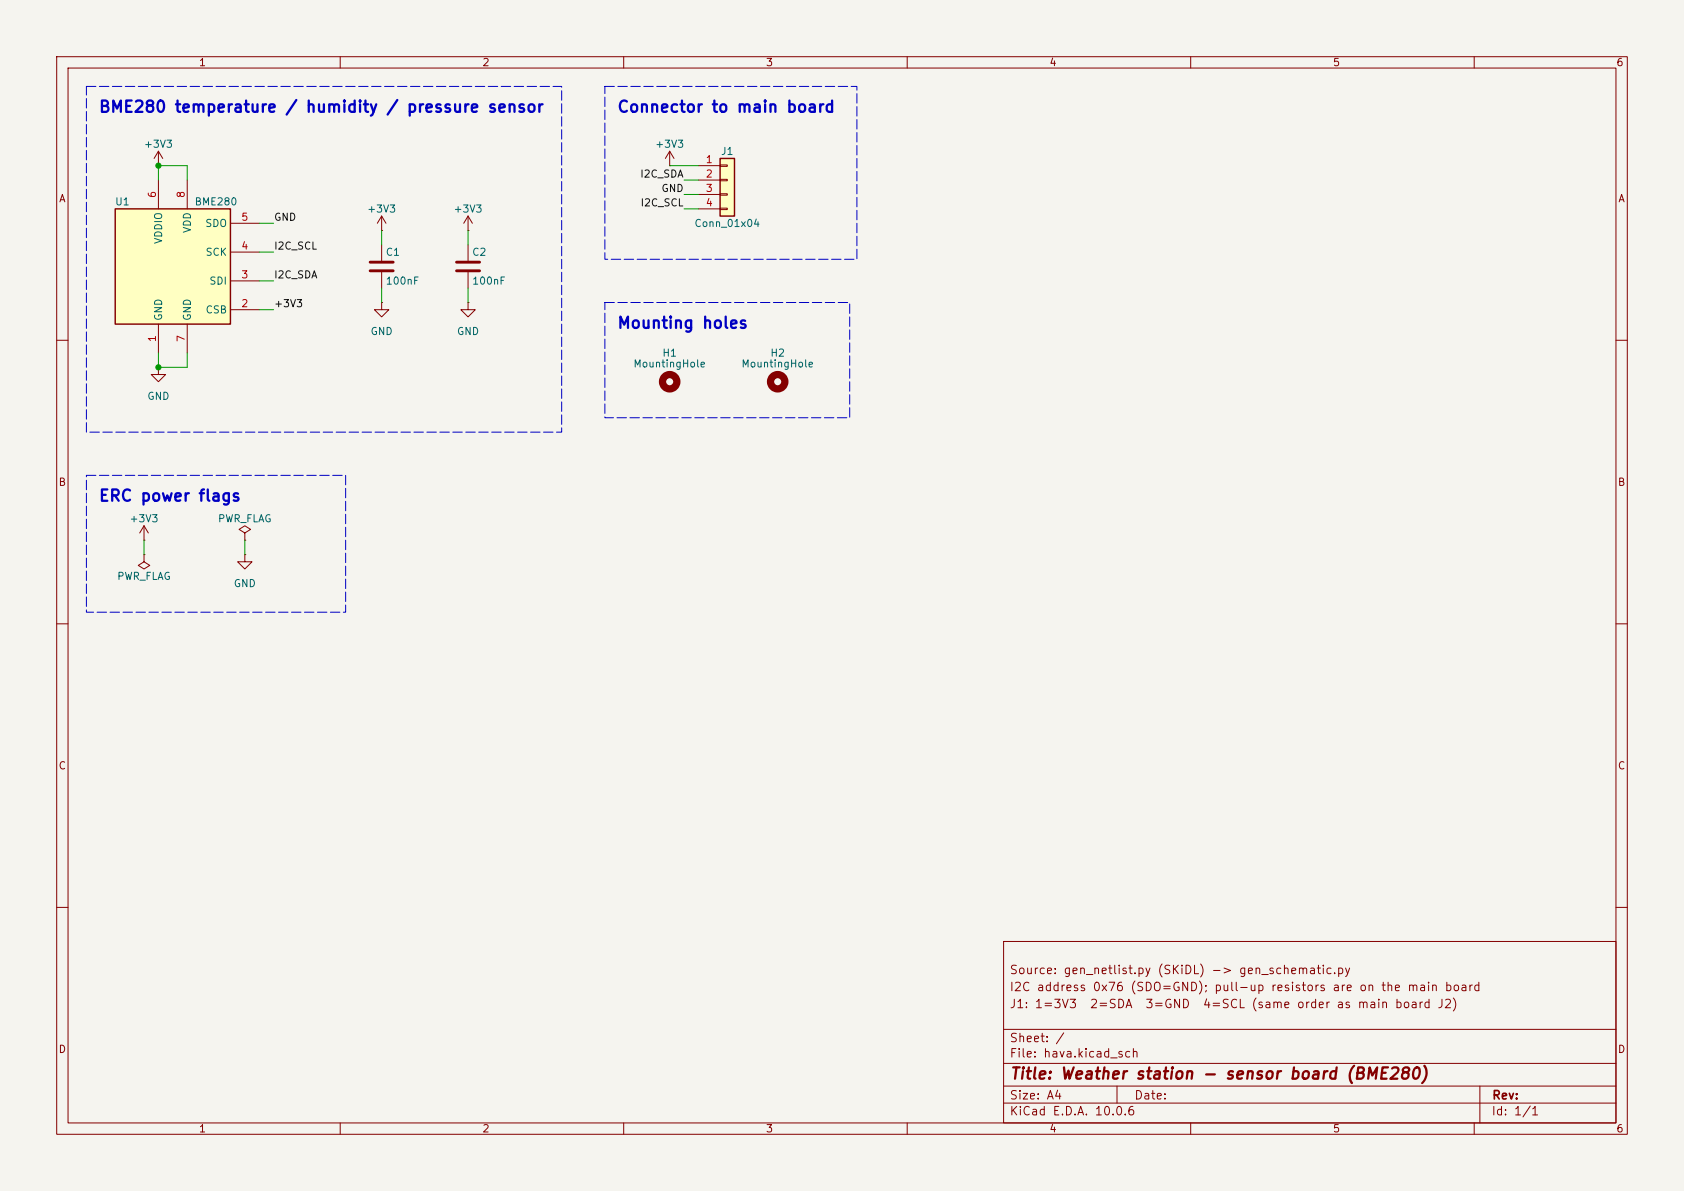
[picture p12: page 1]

Source: gen_netlist.py (SKiDL) -> gen_schematic.py
I2C address 0x76 (SDO=GND); pull-up resistors are on the main board
J1: 1=3V3 2=SDA 3=GND 4=SCL (same order as main board J2)

Sheet: /
File: hava.kicad_sch
Title: Weather station - sensor board (BME280)

Size: A4 | Rev:
KiCad E.D.A. 10.0.6 | Id: 1/1

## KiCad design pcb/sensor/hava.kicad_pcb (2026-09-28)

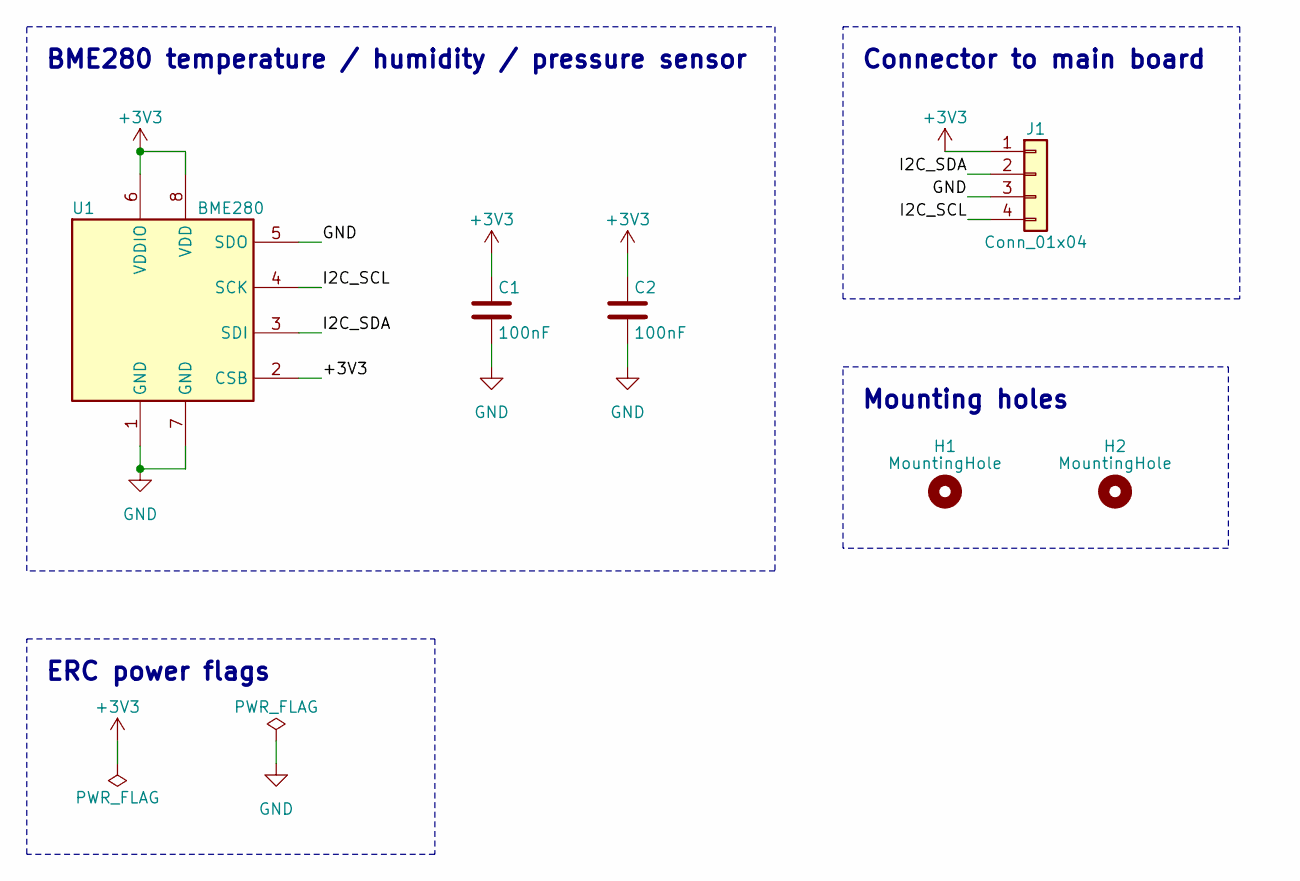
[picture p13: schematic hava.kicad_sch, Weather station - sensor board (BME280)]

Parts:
C1, C2: 100nF; C_0402_1005Metric
H1, H2: MountingHole; MountingHole_2.2mm_M2
J1: Conn_01x04; PinHeader_1x04_P2.54mm_Vertical
U1: BME280; Bosch_LGA-8_2.5x2.5mm_P0.65mm_ClockwisePinNumbering

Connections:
+3V3: C1.1, C2.1, J1.1, U1.2 (CSB), U1.6 (VDDIO), U1.8 (VDD)
/I2C_SCL: J1.4, U1.4 (SCK)
/I2C_SDA: J1.2, U1.3 (SDI)
GND: C1.2, C2.2, J1.3, U1.1 (GND), U1.5 (SDO), U1.7 (GND)

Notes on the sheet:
BME280 temperature / humidity / pressure sensor
ERC power flags
Connector to main board
Mounting holes

Board: 2 copper layers, 6 parts (0 on the bottom side), 4 nets, no tracks yet.

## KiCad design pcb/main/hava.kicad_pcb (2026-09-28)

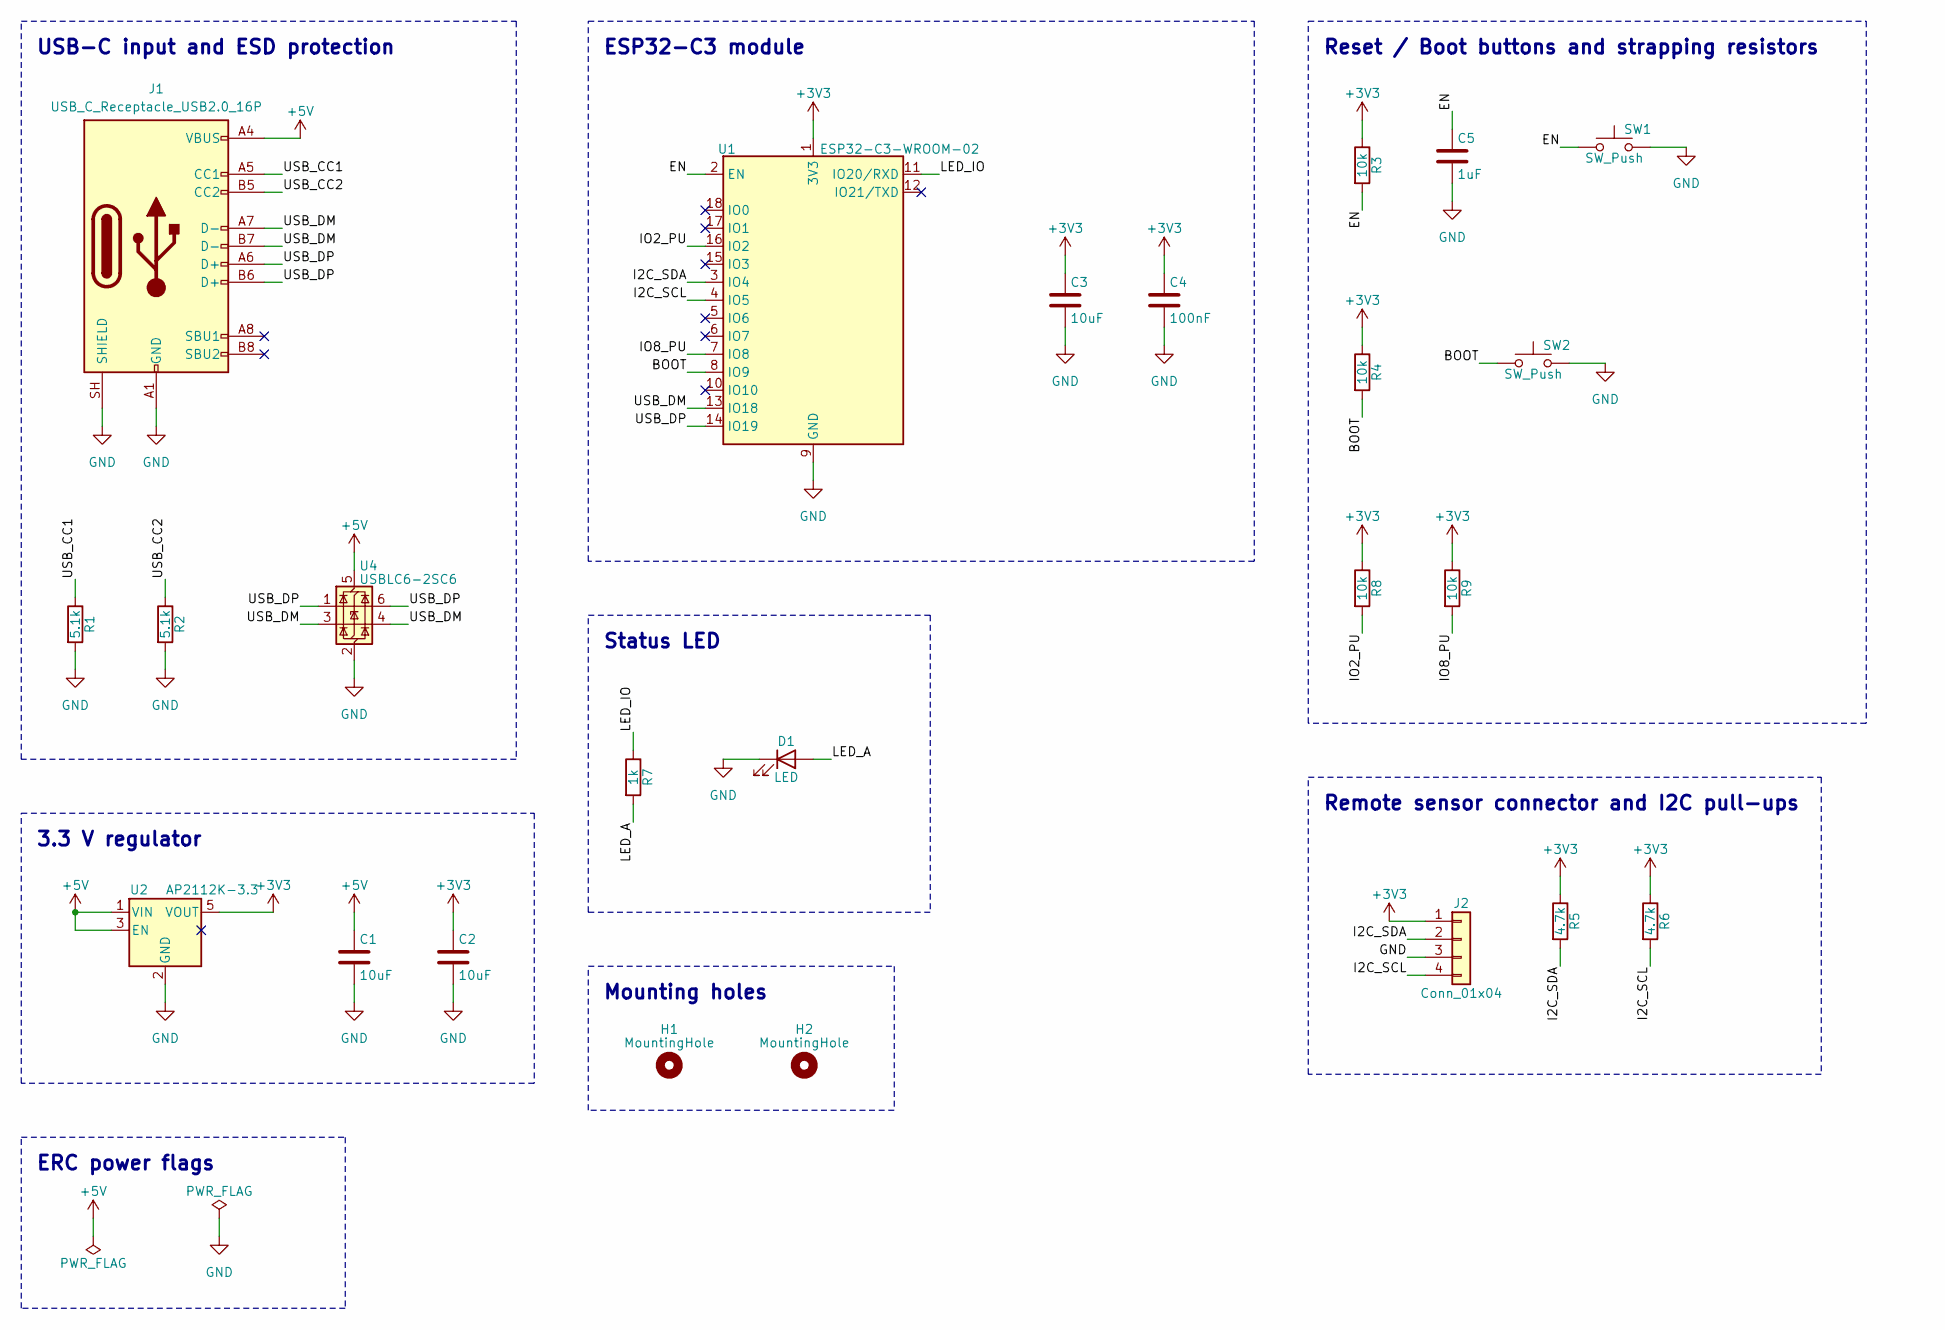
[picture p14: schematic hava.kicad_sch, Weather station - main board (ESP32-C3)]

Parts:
C1, C2, C3: 10uF; C_0805_2012Metric
C4: 100nF; C_0402_1005Metric
C5: 1uF; C_0402_1005Metric
D1: LED; LED_0603_1608Metric
H1, H2: MountingHole; MountingHole_2.2mm_M2
J1: USB_C_Receptacle_USB2.0_16P; USB_C_Receptacle_GCT_USB4105-xx-A_16P_TopMnt_Horizontal
J2: Conn_01x04; PinHeader_1x04_P2.54mm_Horizontal
R1, R2: 5.1k; R_0402_1005Metric
R3, R4, R8, R9: 10k; R_0402_1005Metric
R5, R6: 4.7k; R_0402_1005Metric
R7: 1k; R_0402_1005Metric
SW1, SW2: SW_Push; SW_SPST_B3U-1000P
U1: ESP32-C3-WROOM-02
U2: AP2112K-3.3; SOT-23-5
U4: USBLC6-2SC6; SOT-23-6

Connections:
+3V3: C2.1, C3.1, C4.1, J2.1, R3.1, R4.1, R5.1, R6.1, R8.1, R9.1, U1.1 (3V3), U2.5 (VOUT)
+5V: C1.1, J1.A4 (VBUS), J1.A9 (VBUS), J1.B4 (VBUS), J1.B9 (VBUS), U2.1 (VIN), U2.3 (EN), U4.5 (VBUS)
/BOOT: R4.2, SW2.1, U1.8 (IO9)
/EN: C5.1, R3.2, SW1.1, U1.2 (EN)
/I2C_SCL: J2.4, R6.2, U1.4 (IO5)
/I2C_SDA: J2.2, R5.2, U1.3 (IO4)
/IO2_PU: R8.2, U1.16 (IO2)
/IO8_PU: R9.2, U1.7 (IO8)
/LED_A: D1.2 (A), R7.2
/LED_IO: R7.1, U1.11 (IO20/RXD)
/USB_CC1: J1.A5 (CC1), R1.1
/USB_CC2: J1.B5 (CC2), R2.1
/USB_DM: J1.A7 (D-), J1.B7 (D-), U1.13 (IO18), U4.3 (I/O2), U4.4 (I/O2)
/USB_DP: J1.A6 (D+), J1.B6 (D+), U1.14 (IO19), U4.1 (I/O1), U4.6 (I/O1)
GND: C1.2, C2.2, C3.2, C4.2, C5.2, D1.1 (K), J1.A1 (GND), J1.A12 (GND), J1.B1 (GND), J1.B12 (GND), J1.SH (SHIELD), J2.3, R1.2, R2.2, SW1.2, SW2.2, U1.9 (GND), U1.19 (GND), U2.2 (GND), U4.2 (GND)

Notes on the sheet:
USB-C input and ESD protection
3.3 V regulator
ERC power flags
ESP32-C3 module
Status LED
Mounting holes
Reset / Boot buttons and strapping resistors
Remote sensor connector and I2C pull-ups

Board: 2 copper layers, 24 parts (0 on the bottom side), 15 nets, no tracks yet.

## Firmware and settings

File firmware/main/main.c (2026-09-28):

/* Hava sensor dugumu: olc -> MQTT (WebSocket/TLS) ile yayinla. Bir tarayici sayfasi (web/index.html) ayni konuyu dinler.
 * Sensor: BME280 (sensor karti) veya DHT22 (alternatif). Kart: ESP32-C3 (ana kart) veya ESP32-S3 (simulasyon hedefi). */
#include <stdio.h>
#include <string.h>
#include "freertos/FreeRTOS.h"
#include "freertos/task.h"
#include "freertos/event_groups.h"
#include "esp_log.h"
#include "esp_wifi.h"
#include "esp_event.h"
#include "nvs_flash.h"
#include "mqtt_client.h"
#include "esp_crt_bundle.h"
#include "sdkconfig.h"
#if CONFIG_SENSOR_BME280
#include "driver/i2c_master.h"
#include "bme280.h"
#else
#include "dht22.h"
#endif
#include "display.h"

static const char *TAG = "hava";
static EventGroupHandle_t s_events;
#define WIFI_UP BIT0
static volatile bool s_mqtt_up;

static void wifi_handler(void *arg, esp_event_base_t base, int32_t id, void *data)
{
    if (base == WIFI_EVENT && id == WIFI_EVENT_STA_START) esp_wifi_connect();
    else if (base == WIFI_EVENT && id == WIFI_EVENT_STA_DISCONNECTED) { xEventGroupClearBits(s_events, WIFI_UP); esp_wifi_connect(); }
    else if (base == IP_EVENT && id == IP_EVENT_STA_GOT_IP) xEventGroupSetBits(s_events, WIFI_UP);
}

static void wifi_start(void)
{
    s_events = xEventGroupCreate();
    ESP_ERROR_CHECK(esp_netif_init());
    ESP_ERROR_CHECK(esp_event_loop_create_default());
    esp_netif_create_default_wifi_sta();
    wifi_init_config_t cfg = WIFI_INIT_CONFIG_DEFAULT();
    ESP_ERROR_CHECK(esp_wifi_init(&cfg));
    ESP_ERROR_CHECK(esp_event_handler_register(WIFI_EVENT, ESP_EVENT_ANY_ID, wifi_handler, NULL));
    ESP_ERROR_CHECK(esp_event_handler_register(IP_EVENT, IP_EVENT_STA_GOT_IP, wifi_handler, NULL));
    wifi_config_t wc = { 0 };
    strncpy((char *)wc.sta.ssid, CONFIG_WIFI_SSID, sizeof(wc.sta.ssid) - 1);
    strncpy((char *)wc.sta.password, CONFIG_WIFI_PASSWORD, sizeof(wc.sta.password) - 1);
    ESP_ERROR_CHECK(esp_wifi_set_mode(WIFI_MODE_STA));
    ESP_ERROR_CHECK(esp_wifi_set_config(WIFI_IF_STA, &wc));
    ESP_ERROR_CHECK(esp_wifi_start());
    xEventGroupWaitBits(s_events, WIFI_UP, pdFALSE, pdTRUE, portMAX_DELAY);
    ESP_LOGI(TAG, "Wi-Fi baglandi");
}

static void mqtt_handler(void *arg, esp_event_base_t base, int32_t id, void *data)
{
    if (id == MQTT_EVENT_CONNECTED) { s_mqtt_up = true; ESP_LOGI(TAG, "MQTT baglandi"); }
    else if (id == MQTT_EVENT_DISCONNECTED) { s_mqtt_up = false; ESP_LOGW(TAG, "MQTT koptu"); }
}

typedef struct { float t, h, p; bool has_p; } meas_t;

#if CONFIG_SENSOR_BME280
static bool sensor_init(void)
{
    i2c_master_bus_config_t bc = { .i2c_port = I2C_NUM_0, .sda_io_num = CONFIG_I2C_SDA, .scl_io_num = CONFIG_I2C_SCL,
                                   .clk_source = I2C_CLK_SRC_DEFAULT, .glitch_ignore_cnt = 7 };
    i2c_master_bus_handle_t bus;
    ESP_ERROR_CHECK(i2c_new_master_bus(&bc, &bus));
    bool ok = (bme280_init(bus, 0x76) == ESP_OK);
    if (!ok) ESP_LOGE(TAG, "BME280 bulunamadi (0x76): kablo ve pull-up'lari kontrol et");
    return ok;
}
static bool sensor_read(meas_t *m)
{
    bme280_reading_t r;
    if (bme280_read(&r) != ESP_OK) return false;
    m->t = r.temperature_c; m->h = r.humidity_pct; m->p = r.pressure_hpa; m->has_p = true;
    return true;
}
#else
static bool sensor_init(void) { vTaskDelay(pdMS_TO_TICKS(1500)); return true; }   /* DHT22: guc verdikten sonra 1 sn bekle */
static bool sensor_read(meas_t *m)
{
    m->has_p = false; m->p = 0;
    esp_err_t e = dht22_read(CONFIG_SENSOR_PIN, &m->t, &m->h);
    if (e != ESP_OK) ESP_LOGW(TAG, "DHT22 okunamadi: %s", esp_err_to_name(e));
    return e == ESP_OK;
}
#endif

void app_main(void)
{
    esp_err_t r = nvs_flash_init();
    if (r == ESP_ERR_NVS_NO_FREE_PAGES || r == ESP_ERR_NVS_NEW_VERSION_FOUND) { ESP_ERROR_CHECK(nvs_flash_erase()); r = nvs_flash_init(); }
    ESP_ERROR_CHECK(r);
    display_init();     /* CONFIG_DISPLAY_ST7789 kapaliyken zararsizca hicbir sey yapmaz */
    wifi_start();

    esp_mqtt_client_config_t mc = {
        .broker.address.uri = CONFIG_MQTT_URI,
        .broker.verification.crt_bundle_attach = esp_crt_bundle_attach,
        .credentials.username = CONFIG_MQTT_USER,
        .credentials.authentication.password = CONFIG_MQTT_PASS,
    };
    esp_mqtt_client_handle_t client = esp_mqtt_client_init(&mc);
    esp_mqtt_client_register_event(client, ESP_EVENT_ANY_ID, mqtt_handler, NULL);
    esp_mqtt_client_start(client);

    bool ok = sensor_init();
    for (;;) {
        meas_t m;
        if (ok && sensor_read(&m)) {
            char js[128];
            if (m.has_p) snprintf(js, sizeof(js), "{\"t\":%.2f,\"h\":%.1f,\"p\":%.1f}", m.t, m.h, m.p);
            else         snprintf(js, sizeof(js), "{\"t\":%.2f,\"h\":%.1f}", m.t, m.h);
            ESP_LOGI(TAG, "olcum: %s", js);
            display_show(m.t, m.h, m.p, m.has_p);
            if (s_mqtt_up) esp_mqtt_client_publish(client, CONFIG_MQTT_TOPIC, js, 0, 1, 1);   /* QoS1, retain: sayfa acilinca son degeri gorur */
            else ESP_LOGW(TAG, "MQTT bagli degil, yayin atlandi");
        }
        vTaskDelay(pdMS_TO_TICKS(CONFIG_PUBLISH_SECONDS * 1000));
    }
}

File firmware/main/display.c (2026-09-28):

/* display.c: T-Display-S3'un dahili ekrani (ST7789, 170x320, paralel 8 bit i80 arayuzu).
 * Yalnizca CONFIG_DISPLAY_ST7789 acikken derlenir (bu ekran ana kartta yok, yalnizca T-Display-S3
 * gelistirme kartinda var). Pin numaralari ve gap/swap/mirror ayarlari LilyGO'nun resmi
 * T-Display-S3 ornek projesinden (examples/factory) alindi: https://github.com/Xinyuan-LilyGO/T-Display-S3
 *
 * Font kutuphanesi kullanilmiyor: rakamlar ve C/H/P harfleri 7 parcali gosterge (7-segment) gibi
 * dikdortgenlerle ciziliyor. Bu satirlik olcum degerleri (orn. "22.4C") icin yeterli. */
#include "display.h"
#include "sdkconfig.h"

#if CONFIG_DISPLAY_ST7789
#include <stdio.h>
#include <stdlib.h>
#include "driver/gpio.h"
#include "esp_lcd_panel_io.h"
#include "esp_lcd_panel_vendor.h"
#include "esp_lcd_panel_ops.h"
#include "esp_log.h"

/* LilyGO T-Display-S3 pin haritasi (paralel LCD arayuzu) */
#define PIN_D0  39
#define PIN_D1  40
#define PIN_D2  41
#define PIN_D3  42
#define PIN_D4  45
#define PIN_D5  46
#define PIN_D6  47
#define PIN_D7  48
#define PIN_WR  8
#define PIN_RD  9
#define PIN_DC  7
#define PIN_CS  6
#define PIN_RST 5
#define PIN_BL  38
#define PIN_PWR 15     /* cevre birimleri (ekran dahil) bu pin HIGH olmadan calismiyor */

#define LCD_W 320      /* swap_xy+mirror sonrasi yatay (landscape) gorunum */
#define LCD_H 170
#define COLOR_BG 0x0000
#define COLOR_FG 0x07E0   /* RGB565 yesil */

static const char *TAG = "display";
static esp_lcd_panel_handle_t s_panel;
static uint16_t *s_buf;       /* yeniden kullanilan cizim tamponu, en buyuk ihtiyaca gore ayrilir */

/* 7 parcali gosterge duzeni:
 *    _a_
 *   f   b
 *    _g_
 *   e   c
 *    _d_
 */
#define SEG_A (1 << 0)
#define SEG_B (1 << 1)
#define SEG_C (1 << 2)
#define SEG_D (1 << 3)
#define SEG_E (1 << 4)
#define SEG_F (1 << 5)
#define SEG_G (1 << 6)

static uint8_t seg_pattern(char c)
{
    switch (c) {
        case '0': return SEG_A | SEG_B | SEG_C | SEG_D | SEG_E | SEG_F;
        case '1': return SEG_B | SEG_C;
        case '2': return SEG_A | SEG_B | SEG_G | SEG_E | SEG_D;
        case '3': return SEG_A | SEG_B | SEG_G | SEG_C | SEG_D;
        case '4': return SEG_F | SEG_G | SEG_B | SEG_C;
        case '5': return SEG_A | SEG_F | SEG_G | SEG_C | SEG_D;
        case '6': return SEG_A | SEG_F | SEG_G | SEG_E | SEG_C | SEG_D;
        case '7': return SEG_A | SEG_B | SEG_C;
        case '8': return SEG_A | SEG_B | SEG_C | SEG_D | SEG_E | SEG_F | SEG_G;
        case '9': return SEG_A | SEG_B | SEG_C | SEG_D | SEG_F | SEG_G;
        case 'C': return SEG_A | SEG_F | SEG_E | SEG_D;
        case 'H': return SEG_F | SEG_E | SEG_G | SEG_B | SEG_C;
        case 'P': return SEG_A | SEG_F | SEG_G | SEG_B | SEG_E;
        case '-': return SEG_G;
        default:  return 0;   /* bosluk: hicbir parca yanmaz */
    }
}

#define CW 34   /* karakter kutusu genisligi */
#define CH 46   /* karakter kutusu yuksekligi (satir yuksekligi 170/3=56, ortalamak icin CH<56) */
#define ST 6    /* parca kalinligi */
#define ROW_H (LCD_H / 3)

static void fill_rect(int x, int y, int w, int h, uint16_t color)
{
    if (w <= 0 || h <= 0) return;
    for (int i = 0; i < w * h; i++) s_buf[i] = color;   /* s_buf her zaman en az LCD_W*ROW_H buyuklugunde */
    esp_lcd_panel_draw_bitmap(s_panel, x, y, x + w, y + h, s_buf);
}

static void draw_char(int x0, int y0, char c, uint16_t color)
{
    if (c == '.') { fill_rect(x0 + 4, y0 + CH - ST, ST, ST, color); return; }
    uint8_t seg = seg_pattern(c);
    int hw = CW - 2 * ST;                 /* yatay parca uzunlugu */
    int vh = (CH - 3 * ST) / 2;           /* dikey parca uzunlugu (ust/alt yari) */
    if (seg & SEG_A) fill_rect(x0 + ST, y0, hw, ST, color);
    if (seg & SEG_G) fill_rect(x0 + ST, y0 + ST + vh, hw, ST, color);
    if (seg & SEG_D) fill_rect(x0 + ST, y0 + 2 * ST + 2 * vh, hw, ST, color);
    if (seg & SEG_F) fill_rect(x0, y0 + ST, ST, vh, color);
    if (seg & SEG_E) fill_rect(x0, y0 + 2 * ST + vh, ST, vh, color);
    if (seg & SEG_B) fill_rect(x0 + CW - ST, y0 + ST, ST, vh, color);
    if (seg & SEG_C) fill_rect(x0 + CW - ST, y0 + 2 * ST + vh, ST, vh, color);
}

static void draw_line(int row, const char *text, uint16_t color)
{
    int y = row * ROW_H;
    fill_rect(0, y, LCD_W, ROW_H, COLOR_BG);    /* onceki degeri temizle */
    int x = 4, y0 = y + (ROW_H - CH) / 2;
    for (const char *p = text; *p; p++) {
        draw_char(x, y0, *p, color);
        x += (*p == '.') ? (CW / 2) : CW;
    }
}

void display_init(void)
{
    gpio_config_t pwr_cfg = { .pin_bit_mask = 1ULL << PIN_PWR, .mode = GPIO_MODE_OUTPUT };
    gpio_config(&pwr_cfg);
    gpio_set_level(PIN_PWR, 1);

    gpio_config_t rd_cfg = { .pin_bit_mask = 1ULL << PIN_RD, .mode = GPIO_MODE_OUTPUT };
    gpio_config(&rd_cfg);
    gpio_set_level(PIN_RD, 1);      /* yazma-yalnizca kullanim: RD hep yuksek tutulur */

    gpio_config_t bl_cfg = { .pin_bit_mask = 1ULL << PIN_BL, .mode = GPIO_MODE_OUTPUT };
    gpio_config(&bl_cfg);
    gpio_set_level(PIN_BL, 1);

    esp_lcd_i80_bus_handle_t bus;
    esp_lcd_i80_bus_config_t bus_cfg = {
        .dc_gpio_num = PIN_DC, .wr_gpio_num = PIN_WR, .clk_src = LCD_CLK_SRC_DEFAULT,
        .data_gpio_nums = { PIN_D0, PIN_D1, PIN_D2, PIN_D3, PIN_D4, PIN_D5, PIN_D6, PIN_D7 },
        .bus_width = 8, .max_transfer_bytes = LCD_W * ROW_H * sizeof(uint16_t),
    };
    ESP_ERROR_CHECK(esp_lcd_new_i80_bus(&bus_cfg, &bus));

    esp_lcd_panel_io_handle_t io;
    esp_lcd_panel_io_i80_config_t io_cfg = {
        .cs_gpio_num = PIN_CS, .pclk_hz = 10 * 1000 * 1000, .trans_queue_depth = 10,
        .dc_levels = { .dc_idle_level = 0, .dc_cmd_level = 0, .dc_dummy_level = 0, .dc_data_level = 1 },
        .lcd_cmd_bits = 8, .lcd_param_bits = 8,
    };
    ESP_ERROR_CHECK(esp_lcd_new_panel_io_i80(bus, &io_cfg, &io));

    esp_lcd_panel_dev_config_t panel_cfg = {
        .reset_gpio_num = PIN_RST,
        .rgb_ele_order = LCD_RGB_ELEMENT_ORDER_RGB,  /* IDF < 5.1 ise bu alan yerine .color_space kullanilir */
        .bits_per_pixel = 16,
    };
    ESP_ERROR_CHECK(esp_lcd_new_panel_st7789(io, &panel_cfg, &s_panel));
    ESP_ERROR_CHECK(esp_lcd_panel_reset(s_panel));
    ESP_ERROR_CHECK(esp_lcd_panel_init(s_panel));
    ESP_ERROR_CHECK(esp_lcd_panel_invert_color(s_panel, true));
    ESP_ERROR_CHECK(esp_lcd_panel_swap_xy(s_panel, true));
    ESP_ERROR_CHECK(esp_lcd_panel_mirror(s_panel, false, true));
    ESP_ERROR_CHECK(esp_lcd_panel_set_gap(s_panel, 0, 35));   /* LilyGO'nun resmi ornegindeki deger */
    ESP_ERROR_CHECK(esp_lcd_panel_disp_on_off(s_panel, true));

    s_buf = malloc(LCD_W * ROW_H * sizeof(uint16_t));
    if (!s_buf) { ESP_LOGE(TAG, "cizim tamponu ayrilamadi"); return; }
    fill_rect(0, 0, LCD_W, LCD_H, COLOR_BG);
    ESP_LOGI(TAG, "ekran hazir (%dx%d)", LCD_W, LCD_H);
}
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

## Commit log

2026-09-25 İlk kayıt: hava istasyonu tasarımı ve kodu (v0 ESP32-S3, v1 ESP32-C3)
    v1: SKiDL netlist, pcbnew kart oluşturma, Freerouting yönlendirme (DRC 0),
    ESP-IDF firmware (Wi-Fi, Open-Meteo, BME280, ST7789), host testleri,
    Wokwi yapılandırması ve çalışma günlüğü. Üretim yapılmadı.
    [hava.kicad_pcb, hava_bom.csv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]
2026-09-25 Kutu (FreeCAD), ESP32'siz PC demosu, ikinci datasheet denetimi ve süreç notları
    - case/: kartın ölçülerini KiCad'den okuyup FreeCAD ile kutu ve kapak üretir,
    parçalı 3D kart modeliyle çakışma kontrolü yapar (çakışma 0).
    - firmware/pc_demo: gerçek Open-Meteo verisi + firmware'in gerçek ekran ve
    sensör hesap kodu ile ESP32 olmadan ekran görüntüsü üretir.
    - Kart: IO2 ve IO8 pull-up, BME280 için ikinci 100 nF (datasheet denetimi).
    - docs/SUREC-NOTLARI.md, docs/v1/03-denetim-2.md, çalışma günlüğü güncellendi.
    [base.step, base.stl, hava.kicad_pcb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]
2026-09-25 v2: dıştan ölçüp internete yayınlayan sensör düğümü (yön düzeltmesi)
    İlk cümle "internetten veren sistem" idi; v1 yanlış yönde (internetten çeken)
    yapılmıştı. v2: ana kart (32x41, ESP32-C3, dik açılı sensör konnektörü),
    sensör kartı (14x16, BME280), ana kutu ve radyasyon siperi (FreeCAD, parçalı
    3D modelle çakışma kontrolü), firmware_v2 (ölç + MQTT wss, BME280/DHT22),
    tek dosyalık web sayfası, v2 denetimi ve doğrulama testleri
    (BME280 sanal sensör, DHT22 kod çözme, Wokwi uçtan uca).
    [hava.kicad_pcb, hava_routed.kicad_pcb, main_base.step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]
2026-09-25 Temizlik: eski v0/v1 kaldırıldı, notlar ve README yalnızca v2 için baştan yazıldı
    Eski ESP32-S3 (v0) ve ters yönde yapılan (v1) kart, firmware, kutu ve PC demosu
    kaldırıldı; Git geçmişinde fbf8f51 kaydında duruyor. v2'nin kullandığı iki dosya
    taşındı. Eski denetim belgeleri docs/v2 altına alındı. docs/YAPILACAKLAR.md eklendi.
    [base.step, base.stl, hava.kicad_pcb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]
2026-09-26 Yapılacaklar listesi "nasıl yapılır" adımlarıyla, pin tablosu, delik maddesi kaldırıldı
    - docs/YAPILACAKLAR.md: datasheet kontrolü (tablo/sayfa referansları), prototip
    (T-Display-S3 + DHT22) adım adım, sorun giderme, hocaya mail taslağı.
    - docs/v2/05-pin-tablosu.md: karttan otomatik üretilen pin tablosu.
    - README ve süreç notlarından "delik" maddesi çıkarıldı.
2026-09-26 Sürüm etiketleri kaldırıldı, klasörler sadeleştirildi, README yeniden yazıldı, datasheet kontrolü eklendi
    - pcb/main, pcb/sensor, case, firmware, docs/tasarim: klasör ve dosya adlarından sürüm etiketleri çıkarıldı.
    - README yalnızca yapılan işleri anlatıyor; çalıştırma talimatı docs/CALISTIRMA.md'ye taşındı.
    - docs/tasarim/06-datasheet-kontrolu.md: beş datasheet ile kontrol (5/5 uyuşuyor, 2 düzeltme).
    - pcb/pin_tablosu.py: pin tablosunu karttan üretir.
    - Dahili notlar (günlük, yapılacaklar, süreç notları) depodan çıkarıldı.
    [hava.kicad_pcb, hava_routed.kicad_pcb, main_base.step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]
2026-09-26 Tasarım belgeleri sadeleştirildi ve hoca için yeniden yazıldı
    - docs/tasarim: gereksinim, parça seçimi ve birleştirilmiş datasheet denetimi baştan yazıldı;
    pin tablosu karttan üretiliyor (pcb/pin_tablosu.py).
    - README ve firmware açıklamalarındaki kişisel/prototip ifadeleri çıkarıldı.
    - case betiklerindeki kişisel yollar kaldırıldı (çalışma dizininden çalışır).
2026-09-26 Datasheet denetimi: USB4105 footprint ve USBLC6 pinleri kontrol edildi
2026-09-28 Şematik akışı: kartlar KiCad şematiğinden kuruluyor
    Önceden SKiDL netlistinden doğrudan PCB üretiliyordu, arada şematik yoktu.
    Artık akış: SKiDL devre tanımı -> KiCad şematiği (hava.kicad_sch) -> ERC ->
    şematikten netlist -> PCB yerleşimi -> yol çizimi -> DRC (şematik paritesiyle).
    - pcb/tools/sch_gen.py: netlistten KiCad şematiği üretir (İngilizce blok başlıkları)
    - pcb/tools/check.sh: şematik üretimi, ERC, netlist karşılaştırması, PDF çıktısı
    - pcb/tools/relink_board.py: yolları bozmadan footprint'leri şematiğe yeniden bağlar
    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
    [hava.kicad_pcb, hava.kicad_sch, hava_routed.kicad_pcb]
